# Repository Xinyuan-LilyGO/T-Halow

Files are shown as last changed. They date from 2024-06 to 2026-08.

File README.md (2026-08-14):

<h1 align = "center">🏆 T-Halow 🏆</h1>

<p> 
  
  
  
  
</p>

<!-- * [切换到中文版](./README_CN.md) -->

T-Halow is WiFi Halow, an optimized Wi-Fi solution for iot devices, which has a longer transmission distance while providing the same transmission power of 2.4GHz and 5GHz. T-Halow is equipped with the TX-AH module, which can operate in the 730M-950MHz band, the module can operate in the channel width of 1/2/4/8MHz, and can provide a physical throughput of 150 Kbps to 32.5Mbps.

# Project
There are two different versions of T-Halow, which differ in the way they are paired;

It is important to confirm the version of T-Halow you have.

| - | TIME | LINK | VIDEO |
| :---: | :---: | :---: | :---: |
| VER1 | V1.0 24-08-23 | [VERSION1](./docs/ver1/readme.md) | |
| VER2 | V1.0 24-04-16 | [VERSION2](./docs/ver2/readme.md) | https://www.youtube.com/watch?v=nM2GE8Imshc |

Version 1 and version 2 of T-Halow use the same [AT commands](./docs/AT_cmd.md).

Regarding the SDK of the TX-AH module, Taixin does not provide detailed API instructions. If you want to compile it yourself, you can use this project. [hgSDK](./SDK/hgSDK-v1.6.4.3-29063-wnb)

# Firmware download

If you need to download the TX AH firmware, you can use the following two methods:

| Download firmware via downloader  |[docs](./docs/Firmware_burn_1.md)|
| --- | --- |
| Download firmware via esp32 flash_download_tool  | [docs](./docs/Firmware_burn_2.md) |

# Official document;
TX-AH module official documentation is in Chinese, if you can speak Chinese, this may help you;

More TX-AH module information can be found on the official website，[download](https://taixin-semi.com/en/products/modules#wifi-halow)

| Frequency setting description | [docs](./hardware/TX_AH/泰芯802.11AH%20Frequency%20setting%20description_20231130110312.pdf) |
|:---:|:--- |
| TX-AH-Rx00P Series module technical specification | [docs](./hardware/TX_AH/泰芯802.11ah TX-AH-Rx00P%20Series%20module%20technical%20specification_20231116174457.pdf) |
| TX-AH-Rx00P Bridge instructions | [docs](./hardware/TX_AH//泰芯AH%20Bridge%20instructions_20230908122753.pdf) |
| AH Module AT instruction development guide | [docs](./hardware/TX_AH/泰芯AH%20Module%20AT%20instruction%20development%20guide_20230524100503.pdf) |
| AH Module development board instructions | [docs](./hardware/TX_AH/泰芯AH%20Module%20development%20board%20instructions_20230621205234.pdf) |
| AH Module hardware Design Guide | [docs](./hardware/TX_AH/泰芯AH%20Module%20hardware%20Design%20Guide_20230621170639.pdf) |
| AH Performance test method | [docs](./hardware/TX_AH/泰芯AH%20Performance%20test%20method_20230908122816.pdf) |
| AH-RF EMC Certification guide | [docs](./hardware/TX_AH/泰芯AH-RF EMC%20Certification%20guide_20230720140052.pdf) |

# TX-AH model comparison

| Module name | Front screen distinction | Overcertified condition | remark |
| :---: | :---: | :---: | :---: |
| TX-AH-R900P | Lower left P9, lower right P9  | Can pass FCC/CE certification | Supports 860MHz to 928MHz |
| TX-AH-R900PNR | Lower left P9, lower right NR |  Can pass FCC certification | Support 902MHz ~ 928MHz, with 915M Saw to improve receiving performance |
| TX-AH-R900PNR-860M | Lower left 86, lower right NR | Can pass CE certification | Support 859MHz ~ 894MHz, with 875M Saw to improve reception performance |

remark:
1. The difference between the P series module and the earlier A series module is:

(1) The bottom left screen print of the P series is beginning with P, and the bottom left screen print of the A series is beginning with R;

(2) P series PIN4/5 needs power supply, A series does not;

2. The module does not have a Shield by default. The name of the module with a shield is suffix-s, where S indicates shield.

## :three: Quick Start 🎁

🟢 PlatformIO is recommended because these examples were developed on it. 🟢 

### 1、PlatformIO

1. Install [Visual Studio Code](https://code.visualstudio.com/) and [Python](https://www.python.org/), and clone or download the project;
2. Search for the `PlatformIO` plugin in the `VisualStudioCode` extension and install it;
3. After the installation is complete, you need to restart `VisualStudioCode`
4. After opening this project, PlatformIO will automatically download the required tripartite libraries and dependencies, the first time this process is relatively long, please wait patiently;
5. After all the dependencies are installed, you can open the `platformio.ini` configuration file, uncomment in `example` to select a routine, and then press `ctrl+s` to save the `.ini` configuration file;
6. Click :ballot_box_with_check: under VScode to compile the project, then plug in USB and select COM under VScode;
7. Finally, click the :arrow_right:  button to download the program to Flash;

### 2、Arduino IDE

1. Install [Arduino IDE](https://www.arduino.cc/en/software)

2. Copy all files under `this project/lib/` and paste them into the Arduion library path (generally `C:\Users\YourName\Documents\Arduino\libraries`);

3. Open the Arduion IDE and click `File->Open` in the upper left corner to open an example in `this project/example/xxx/xxx.ino` under this item;

4. Then configure Arduion. After the configuration is completed in the following way, you can click the button in the upper left corner of Arduion to compile and download;

| Arduino IDE Setting | Value |
| --- | --- |
| Board | **ESP32S3 Dev Module** |
| Port | Your port |
| USB CDC On Boot | Enable |
| CPU Frequency | 240MHZ(WiFi) |
| Core Debug Level | None |
| USB DFU On Boot | Disable |
| Erase All Flash Before Sketch Upload | Disable |
| Events Run On | Core1 |
| Flash Mode | QIO 80MHZ |
| Flash Size | **16MB(128Mb)** |
| Arduino Runs On | Core1 |
| USB Firmware MSC On Boot | Disable |
| Partition Scheme | **16M Flash(3M APP/9.9MB FATFS)** |
| PSRAM | **OPI PSRAM** |
| Upload Mode | **UART0/Hardware CDC** |
| Upload Speed | 921600 |
| USB Mode | **CDC and JTAG** |

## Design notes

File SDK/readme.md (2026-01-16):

## T-Halow SDK Description

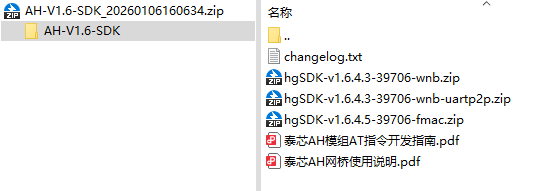
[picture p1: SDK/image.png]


The AH-V1.6-SDK package contains three AH module projects.
Each project can be compiled independently.

The AH-V1.6-SDK development environment requires the installation of the CDK environment.
For environment setup, please refer to 《泰芯TXW830x AH-SDK开发指南.pdf》.

The file descriptions are as follows:

| File | Description |
| :--- | :--- |
| hgSDK-v1.6.4.3-39706-wnb | -wnb corresponds to the Ethernet interface |
| hgSDK-v1.6.4.3-39706-wnb-uartp2p | -uartp2p serial port transparent transmission |
| hgSDK-v1.6.4.5-39706-fmac | -fmac corresponds to SDIO / UART / USB interfaces |
| 泰芯AH模组AT指令开发指南 | AT command description |
| 泰芯AH网桥使用说明 | Bridge configuration instructions |

`-wnb` is an Ethernet interface project. The main communication method is Ethernet communication, supporting TCP/UDP protocols with a communication speed of 90 Mbit/s.
The default serial port baud rate is 115200, which is used for sending and receiving AT commands and outputting debug information. It also supports a small amount of data transmission via the serial port.

`-uartp2p` is a serial port transparent transmission project. After successful pairing, data can be transmitted directly through the serial port. The transmission rate is affected by the serial port baud rate.
The default serial port baud rate is 115200. The baud rate can be modified by changing the `UART_P2P_BAUDRATE` definition.

Note that:

1. The packet length must be limited to 1500 bytes.

2. The baud rate should not be too high; otherwise, there is a risk of data loss. Generally, 400 kbps is recommended as an upper limit. At 921600, there is a relatively high risk of data loss.

`-fmac` is a communication project based on SDIO/SPI, UART, and USB interfaces. The primary communication methods are SDIO/SPI, UART, and USB. Taking SPI communication as an example, the data rate is approximately 25 Mbit/s.
The default serial port baud rate is 115200, which is used for sending and receiving AT commands and for outputting debug information. It also supports a small amount of data transmission via the serial port.

## T-Halow SDK Firmware Description

| File | Description |
| :--- | :--- |
| huge-ic-ah_v1.6.4.3-39706_wnb_sta_8.bin | **-wnb firmware**, maximum number of connected STAs is **8**, AT serial port baud rate **115200** |
| huge-ic-ah_v1.6.4.3-39706_wnb_sta_1.bin | **-wnb firmware**, maximum number of connected STAs is **1**, AT serial port baud rate **115200** |
| huge-ic-ah_v1.6.4.3-39706_wnb_uartp2p_baud_115200.bin | **-uartp2p** serial transparent transmission, baud rate **115200** |
| huge-ic-ah_v1.6.4.3-39706_wnb_uartp2p_baud_230400.bin | **-uartp2p** serial transparent transmission, baud rate **230400** |
| huge-ic-ah_v1.6.4.3-39706_wnb_uartp2p_baud_460800.bin | **-uartp2p** serial transparent transmission, baud rate **460800** |
| huge-ic-ah_v1.6.4.3-39706_wnb_uartp2p_baud_921600.bin | **-uartp2p** serial transparent transmission, baud rate **921600** |

## T-Halow Firmware Download

There is no interface on the T-Halow board for flashing firmware to the HaLow module, so the only option is to remove the HaLow module’s flash memory, place it into a programmer to download the firmware, and then reinstall the flash back to its original position after programming is complete.

Reference:

If you need to download the TX AH firmware, you can use the following two methods:

| Download firmware via downloader  |[docs](../docs/Firmware_burn_1.md)|
| --- | --- |
| Download firmware via esp32 flash_download_tool  | [docs](../docs/Firmware_burn_2.md) |

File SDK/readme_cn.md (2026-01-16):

## T-Halow SDK 说明



AH-V1.6-SDK 文件里面共包含三个 ah 模块的项目，每个项目可以独立编译；

AH-V1.6-SDK 编程环境需要安装 CDK 环境，环境搭建参考《泰芯TXW830x AH-SDK开发指南.pdf》

文件说明如下；

| 文件 | 说明 |
| :--- | :--- |
| hgSDK-v1.6.4.3-39706-wnb | -wnb 对应以太网接口 |
| hgSDK-v1.6.4.3-39706-wnb-uartp2p | -uartp2p 串口透传 |
| hgSDK-v1.6.4.5-39706-fmac | -fmac 对应 sdio uart usb 接口 |
| 泰芯AH模组AT指令开发指南 | AT 指令说明 |
| 泰芯AH网桥使用说明 | 网桥配置说明 |

`-wnb` 为以太网接口项目，主要通信方式为以太网通信，支持 tcp/upd 协议，通信速率为90mbit/s；默认串口波特率为 115200 用于收发 AT 指令，和输出调试信息，支持少量数据通过串口传输；

`-uartp2p` 为串口透传项目，配对成功后，可以直接通过串口传输数据，传输速率受串口波特率影响；串口默认波特率为 115200，可以更改 UART_P2P_BAUDRATE 定义来更改波特率；需要注意的是：

1. 包长要受限于1500字节。
2. 波特率不能太高，否则会有丢数风险，一般建议400k就不敢更高了，921600是有比较大丢数风险的

`-fmac` 为 sdio/spi、uart、usb 接口通信项目，主要通信方式为sdio/spi、uart、usb，以spi通信为例，通信速率为25mbit/s左右； 默认串口波特率为 115200 用于收发 AT 指令，和输出调试信息，支持少量数据通过串口传输；

## T-Halow SDK 固件说明

| 文件 | 说明 |
| :--- | :--- |
| huge-ic-ah_v1.6.4.3-39706_wnb_sta_8.bin | -wnb 固件，连接sta最大数量为8，at串口波特率115200 |
| huge-ic-ah_v1.6.4.3-39706_wnb_sta_1.bin | -wnb 固件，连接sta最大数量为1，at串口波特率115200 |
| huge-ic-ah_v1.6.4.3-39706_wnb_uartp2p_baud_115200.bin | -uartp2p 串口透传，波特率为 115200 |
| huge-ic-ah_v1.6.4.3-39706_wnb_uartp2p_baud_230400.bin | -uartp2p 串口透传，波特率为 230400 |
| huge-ic-ah_v1.6.4.3-39706_wnb_uartp2p_baud_460800.bin | -uartp2p 串口透传，波特率为 460800 |
| huge-ic-ah_v1.6.4.3-39706_wnb_uartp2p_baud_921600.bin | -uartp2p 串口透传，波特率为 921600 |

## T-Halow 固件下载

T-Halow 上面没有为 Halow 模块烧录固件的接口，所以只能将 Halow 模块的flash 去下，放入烧录器中下载程序，烧录完程序后再将 flash 放回原来的位置；

参考：

If you need to download the TX AH firmware, you can use the following two methods:

| Download firmware via downloader  |[docs](../docs/Firmware_burn_1.md)|
| --- | --- |
| Download firmware via esp32 flash_download_tool  | [docs](../docs/Firmware_burn_2.md) |

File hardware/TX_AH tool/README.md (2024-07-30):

This article is taken from: TX_AH\泰芯AH Bridge instructions_20230908122753.pdf

2.2 Flow test method

2.2.1 Preparing Tools

- Two windows PCS with cable network ports. (If no cable network port is available, switch from usb to cable network port.

Can also)

- Two network cables

- A pair of Thai core bridge (including host, antenna, 5v power supply) successfully paired according to the pairing method section.

- jperf(provided by contact FAE)

2.2.2 Traffic test method

2.2.2.1 The first step is to connect the computer to the network bridge using network cables

Connect a computer with a network cable to a bridge

Use a second cable to connect the other computer to the bridge

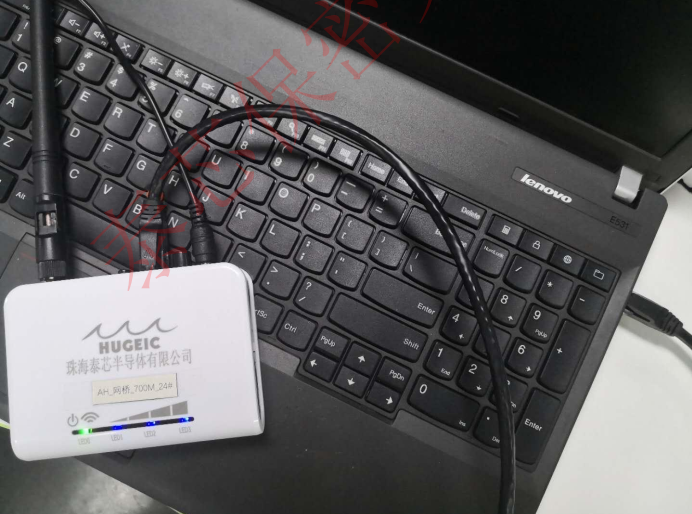
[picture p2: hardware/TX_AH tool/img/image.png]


2.2.2.2 Step 2 Configure wired network ip addresses for the two computers

Open `Control Panel \ Network and Internet\ Network and Sharing Center` Click Ethernet as shown below

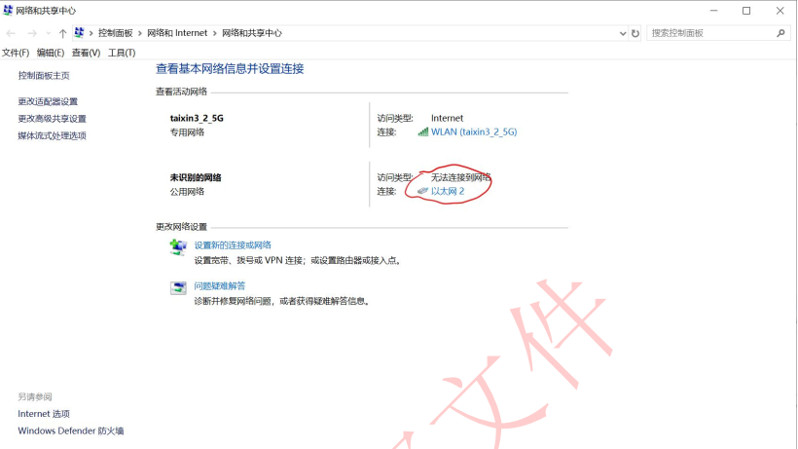
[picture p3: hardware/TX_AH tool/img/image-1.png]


Click properties as shown below

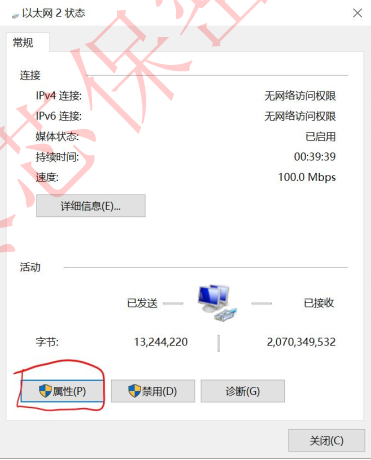
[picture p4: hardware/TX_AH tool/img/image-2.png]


Click the internet Protocol version option and click Properties as shown below

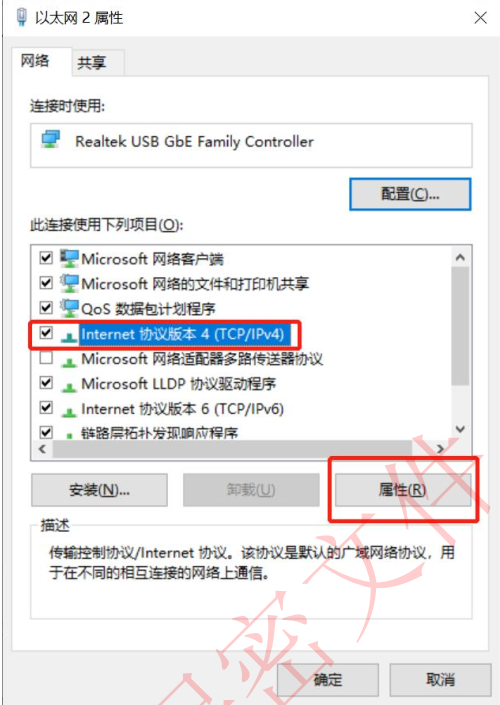
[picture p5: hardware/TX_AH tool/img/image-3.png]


Configure the IP address of the cable network. For example, set the IP address to `10.10.10.156` on one PC and `10.10.10.123` on the other PC

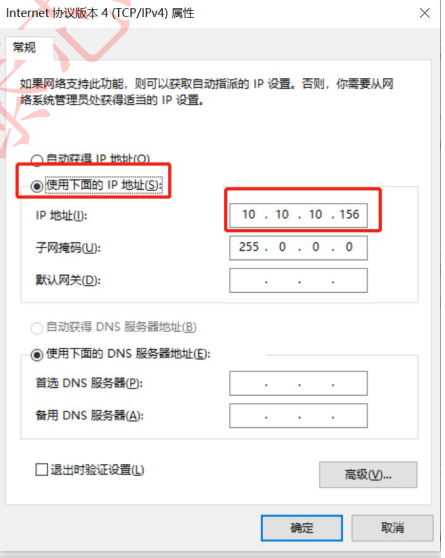
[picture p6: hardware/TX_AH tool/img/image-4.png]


2.2.2.3 Step 3 Disable the firewall temporarily

If iperf is used as the traffic test method, disable the firewall; otherwise, the traffic test cannot be performed.

The following only describes the method of closing the firewall of windows. For the firewall of other security software, please find the method of closing:

1. `win+r` to bring up the running screen, enter cmd, and press Enter
2. In the cmd window that is displayed, enter `Firewall.cpl` and press Enter
3. In the firewall page that pops up, click "Enable or disable Windows Defender Firewall" options

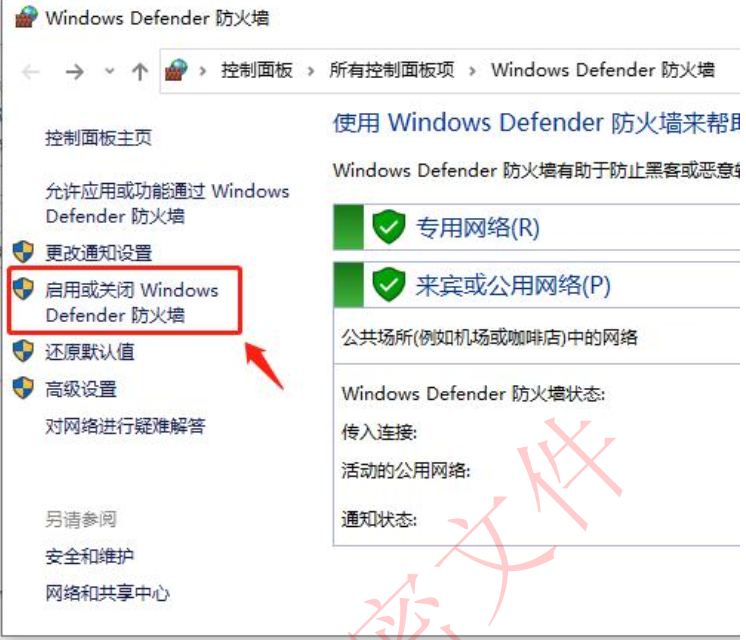
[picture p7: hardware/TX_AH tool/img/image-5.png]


4. In the pop-up "Custom Settings" page, select the "Turn off Windows Defender Firewall" option for all, and then click OK

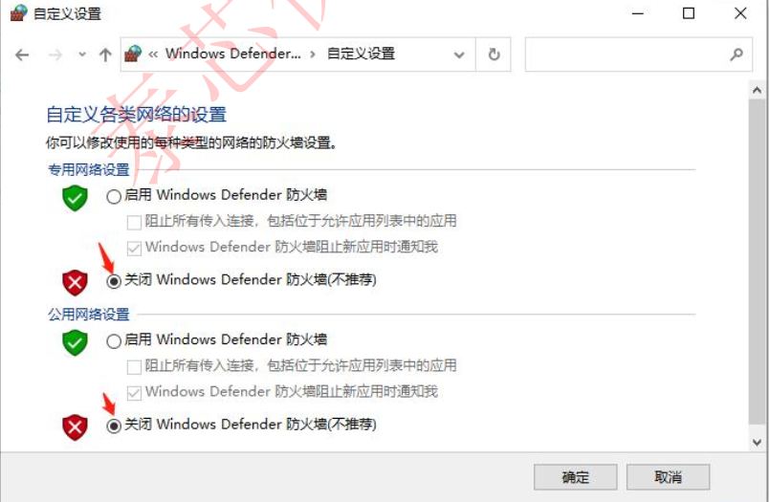
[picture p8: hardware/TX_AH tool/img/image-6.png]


5. After the traffic test is complete, enable the firewall again on the page shown in Step 4.

2.2.2.4 Step 4 Run the jperf to send traffic

1.tcp test:

Run jperf on the first computer (ip address 10.10.10.156, bridge in ap mode). transport layer options Select tcp(tcp by default). Choose iperf mode :server, that is, as the server. Then click run iperf.

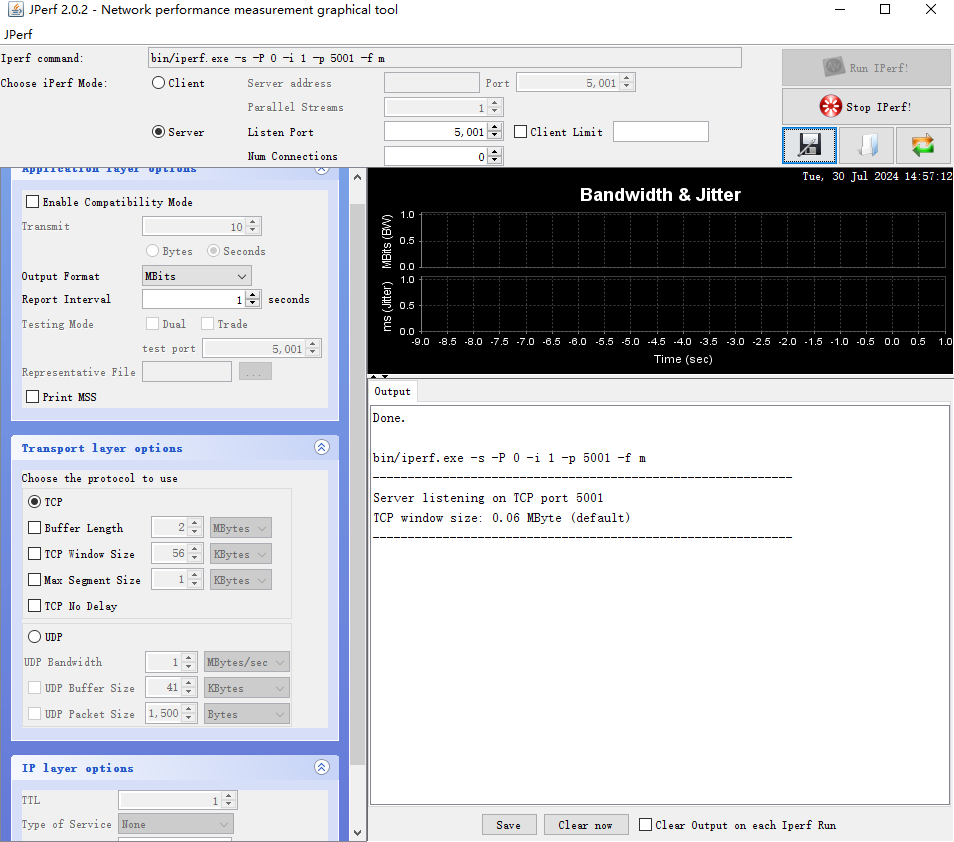
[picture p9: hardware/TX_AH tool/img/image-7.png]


Run jperf on the second computer (ip address 10.10.10.123, bridge in sta mode). transport layer options Select tcp(tcp by default).

Choose iperf mode :client, that is, as the client. Server adress enters the ip address of the other computer, which is 10.10.10.156. Port 5001 is the default port number. The port number on the server and client must be the same.

You can change the traffic test duration (for example, 600 seconds) in the transmit item of the Application layer options. Set output format to a traffic unit, for example, Mbits. Then click run iperf.

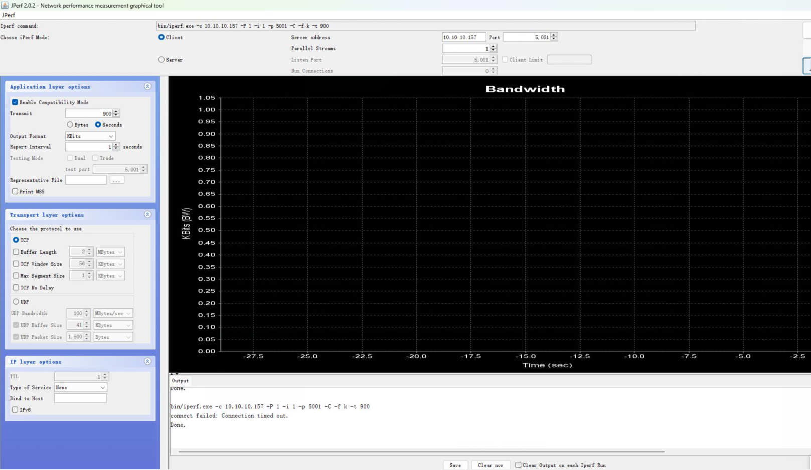
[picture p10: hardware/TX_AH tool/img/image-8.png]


2.udp test

As with the tcp test, the first computer runs jperf and selects udp in the transport layer options.

Choose iperf mode :server, as the server, and click run iperf.

Run jperf on the second computer and select udp in transport layer options.

Choose iperf mode :client. That is, as the client, set udp bandwidth to

100 (default is 1). Server adress Enter the ip address of the other computer. Port 5001 is the default port number, the same for the server and the client, and then click run iperf. Observe the traffic data on the server.

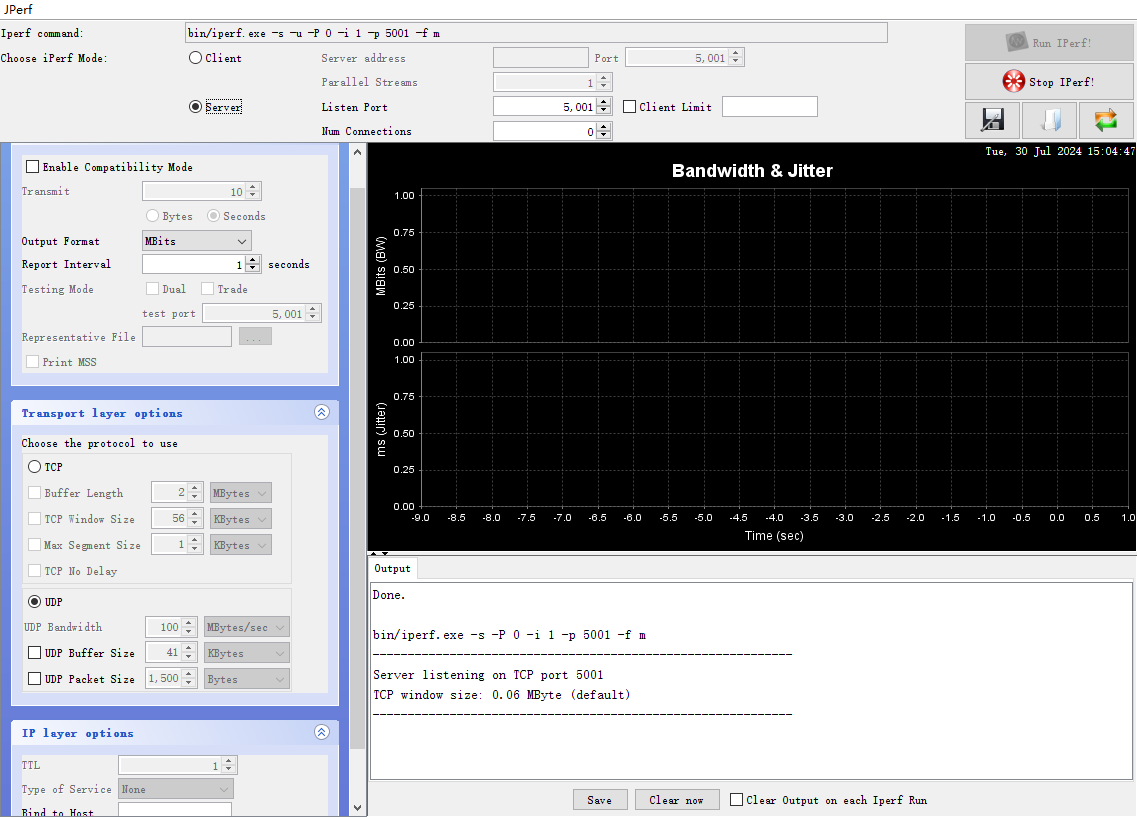
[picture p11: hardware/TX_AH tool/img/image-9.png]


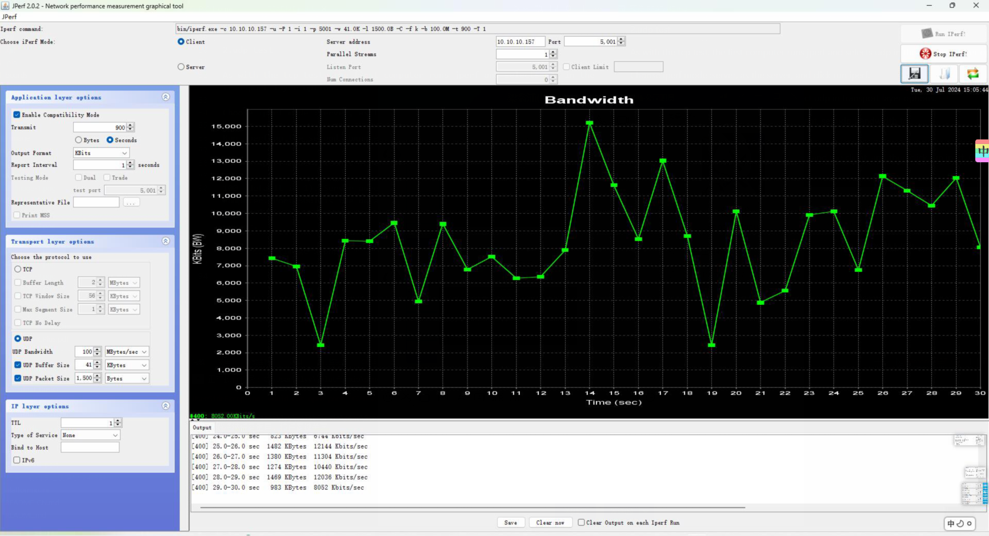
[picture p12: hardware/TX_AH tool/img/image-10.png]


At present, the bridge design is sta to the ap direction of traffic priority, if the exchange of traffic direction to ap to sta direction, the traffic will be slightly smaller

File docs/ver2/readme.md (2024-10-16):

# T_Halwo Version2

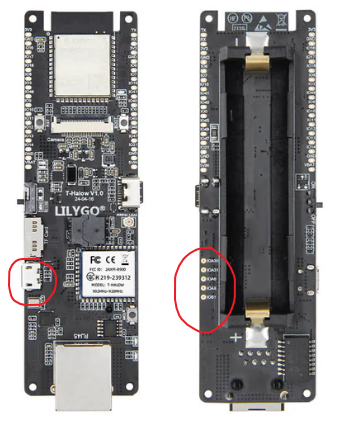
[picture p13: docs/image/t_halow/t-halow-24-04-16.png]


T-Halow operates in two modes:

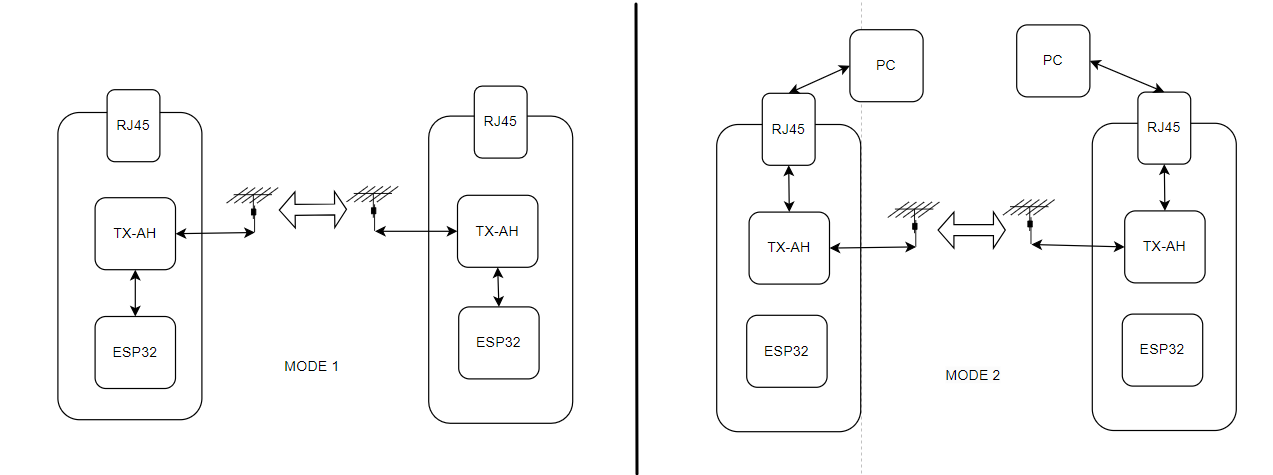
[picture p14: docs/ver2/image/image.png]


The two modes differ：

~~~
MODE1: Send AT command control to TX-AH via ESP32
    TX-AH: Download huge-ic-ah_xxxxxxxxx_TAIXIN-usb.bin
    ESP32: Download AP or STA
    Notice：Debug using Type-C

MODE2: Send AT command control via micro-USB
    TX-AH: download huge-ic-ah_xxxxxxxxx_TAIXIN-WNB.bin
    ESP32: No firmware download required
    Notice：Debug using Micro-USB
~~~

Firmware file path `firmware\version2`.



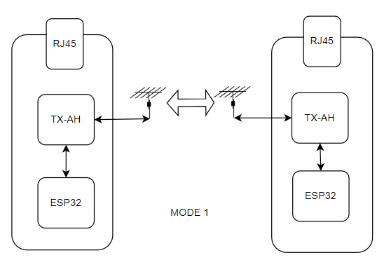
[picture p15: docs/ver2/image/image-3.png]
| T-Halow starts with MODE 1 | [docs](../mode1_test.md)  |  |
| --- | --- | --- |
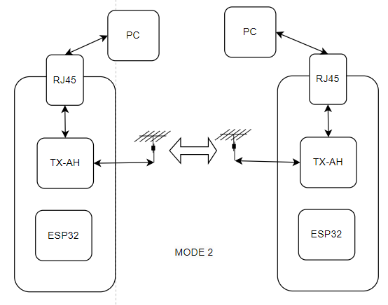
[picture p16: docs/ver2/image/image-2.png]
| T-Halow starts with MODE 2 | [docs](../mode2_test.md)  |  |
| TX-AH module pairing | [docs](./module_pair.md) |

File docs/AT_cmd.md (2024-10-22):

# AT 命令

Taixin AH module supports AT command working mode, and can send AT command through uart Data setting, data communication.

Note Select the new line mode in the serial port tool, and the AT command is case insensitive.

# Basic networking commands

## `AT+MODE`

Set the working mode；AT+MODE=[param]；Supports parameter : ap / sta / group / apsta

example：

```txt
AT+MODE?		// Inquire
AT+MODE=AP      // AP mode
AT+MODE=STA  	// STA mode 
AT+MODE=GROUP	// Multicast/broadcast mode, see description of `JOINGROUP`
AT+MODE=APSTA	// In trunk mode, the device in trunk mode connects to the 
				// upper-level AP as a sta and provides connection services 
				// for other STAs as an ap. Use `at+r_ssid` and `at+r_psk` to set 
				// connection parameters for the upper AP.
```

## `AT+SSID`

Set the SSID；AT+SSID=[ssid_char]；ssid_char contains less than 32 characters

example：

```txt
AT+SSID? 				// Inquire
AT+SSID=hgic_ah_test	// Set the SSID to `hgic_ah_test`
```

## `AT+KEYMGMT`

Set encryption mode；AT+KEYMGMT=[param]；Supports parameter : WPA-PSK/NONE

example :

```txt
AT+KEYMGMT?			// Inquire
AT+KEYMGMT=WPA-PSK	// Enable encryption
AT+KEYMGMT=NONE		// Turn off encryption
```

## `AT+PSK`

Set encryption password；AT+PSK=[psk_char]；psk_char must be 64 hex characters. If the setting does not meet the length requirements, the previous will be cleared Save the PSK

example：

```txt
AT+PSK?																		// Inquire
AT+PSK=baa58569a9edd7c3a55e446bc658ef76a7173d023d256786832474d737756a82		// Set encryption password
```

## `AT+PAIR`

Pairing control；AT+PAIR=[0/1]

This command can achieve quick pairing and network configuration when the SSID is not set. When pairing starts:

1. The AP has configured the SSID and password, but the STA has not: During the pairing process, the STA will obtain the AP's SSID and password.

2. Both the AP and the STA have not configured the SSID and password: During the pairing process, the AP will generate a random password for each STA.

A PAIR SUCCESS message will be generated after the pairing is successful, but the pairing will not automatically terminate. The pairing must be stopped by executing `AT+PAIR=0`.

The connection will be established automatically after the pairing is stopped.

If both the AP and the STA have set the SSID and other parameters, the PAIR does not need to be started. The connection will be established automatically based on the SSID and other parameters.

example：

```txt
AT+PAIR=1 	// Start pairing
AT+PAIR=0 	// Stop pairing
```

## `AT+BSS_BW`

Set the BSS bandwidth；AT+BSS_BW=[bss_bw]；Supports parameter：1 / 2 / 4 / 8

```txt
AT+BSS_BW?		// Inquire
AT+BSS_BW=1		// Set the bandwidth to 1
AT+BSS_BW=2		// Set the bandwidth to 2
AT+BSS_BW=4		// Set the bandwidth to 4
AT+BSS_BW=8		// Set the bandwidth to 8
```

## `AT+FREQ_RANGE`

Set the operating frequency range；AT+FREQ_RANGE=[start,end]；

This command is used to set the frequency range for continuous use and specify the start and end center frequency. The AH module automatically calculates the frequency list.

Note：that if `AT+CHAN_LIST` is also set, the CHAN_LIST parameter takes precedence

example:

```txt
AT+FREQ_RANGE?				// Inquire
AT+FREQ_RANGE=9080,9240	 	// start freq 908Mhz, end freq 924Mhz
```

## `AT+CHAN_LIST`

Set the working frequency list；AT+CHAN_LIST=[freq1, freq2, ...]；

This command is used to set the non-continuous frequency list. Supports a maximum of 16 frequency points separated by commas (,)

```txt
AT+CHAN_LIST?					// Inquire
AT+CHAN_LIST=9080, 9160, 9240	// Set three frequency points: 908MHz,916MHz,924Mhz
```

# Status query command

## `AT+RSSI`

Check the device signal quality RSSI；AT+RSSI=[index/mac_addr]

Parameter description：

* index：Specify the device index to be queried, starting from 1
* mac_addr：Specify the mac address of the device to be queried

example：

```txt
AT+RSSI?  					// Query the rssi of the first device
AT+RSSI=1					// Query the rssi of the first device
AT+RSSI=f4:de:09:68:6c:20	// Query the RSSI by MAC address
```

## `AT+CONN_STATE`

View connection status；

example：

```txt
AT+CONN_STATE
```

## `AT+WNBCFG`

View device parameters；

example：

```txt
AT+WNBCFG
```

## `AT+SCAN_AP`

Scan for AP information；

This command is executed in STA mode to scan for AP information.

After scanning, query the results with the following BSSLIST command.

example：

```txt
AT+SCAN_AP=2
```

## `AT+BSSLIST`

Get the list of scanned aps;

After running the scan_ap command, you can use this command to obtain the AP list to be scanned. (The ap can be scanned only after ssid is set.)

example：

```txt
AT+BSSLIST
```

# Advanced networking commands

## `AT+TXPOWER`

Set the maximum transmit power；AT+TXPOWER=[txpower]；The range of txpower is [6 , 20]

example：

```txt
AT+TXPOWER?		// Inquire
AT+TXPOWER=20	// Set transmit power 20dbm
```

## `AT+ACKTMO`

Set the ACK TIMEOUT period；AT+ACKTMO=0；Default value. No additional ACK timeout period is added

Parameter description：

Set the WiFi protocol parameter ack timeout value of the AH module. The unit is microsecond. The default value is 0.

You need to set this parameter only when the communication exceeds 1km.

The formula is 10* (distance in kilometers -1), for example 2km set acktmo=10.

Modified value Power-off Save.

example：

```txt
AT+ACKTMO?		// Inquire
AT+ACKTMO=10	// Increase the ACK packet timeout period by 10us
```

## `AT+TX_MCS`

Set the TX MCS；AT+TX_MCS=255；Default value is 255, auto MCS；The value ranges [0, 7]

Parameter description：

Set tx mcs. When the value ranges from 0 to 7 or 1M, 10 indicates that the mcs is fixed. Other values indicate that the mcs is automatically adjusted.

Modified value Power-off Save.

example：

```txt
AT+TX_MCS?		// Inquire
AT+TX_MCS=2 	// The MCS for fixed transmission is 2
```

## `AT+HEART_INT`

Set the heartbeat packet interval；AT+HEART_INT=500；Default value is 500；

Parameter description：

Set the heartbeat packet interval (unit: mS) to 500. The larger the number of STAs, the larger the recommended heartbeat packet interval. The approximate length of heartbeat packets is STA_count x 50

V1.6.2 As long as the AP heartbeat packet interval can be set, the AP will automatically synchronize to the STA, this command is invalid for the STA

Modified value Power-off Save.

example：

```txt
AT+HEART_INT?			// Inquire
AT+HEART_INT=2000		// Set the heartbeat packet interval to 2S
```

## `AT+UNPAIR`

Set unpair a specified STA；AT+UNPAIR=[mac_addr]；mac_addr is the mac address of the peer；

example：

```txt
AT+MAC_ADDR=?					// View the MAC address of the device
AT+UNPAIR=f6:de:09:75:a3:61		// Unpair
```

# Debugging command

## `AT+LOADDEF`

factory data reset；

example：

```txt
AT+LOADDEF=1
```

## `AT+SYSDBG`

Set print debugging information；AT+SYSDBG=XXX,VALE；

Parameter description：

* XXX：Optional value LMAC / WNB

  * LMAC：Air interface statistics
  * WNB：Network layer statistics
* VALE：Optional value 0 / 1

  * 0：Close corresponding print
  * 1：Opencorresponding print

example：

```txt
AT+SYSDBG=LMAC,0	// Disable LMAC printing
```

# Multicast related commands

## `AT+JOINGROUP`

Adding a multicast network；AT+JOINGROUP=group_addr,AID；

Notice the JOINGROUP command can be configured only after the `AT+MODE=GROUP` mode is set.

Parameter description：

* group_addr：Specifies the address of the multicast network to be added
* AID：The AID value of the device in the multicast network ranges from 1 to N (N is the maximum number of STAs supported by the firmware). The AID of each device on the network should be unique.

  * Set valid AID: The WiFi module will periodically send a heartbeat in the multicast network to announce its existence to other WiFi modules
  * Invalid AID: The WiFi module does not send a heartbeat or notify other WiFi modules. **If AID is set to 0 for all devices, there is no limit to the maximum number of STAs supported by the firmware**.

After setting the working mode of the WiFi module to group, you can run this command to add the WiFi module to a multicast network.

After joining a multicast network, the WiFi module will only receive data from that multicast network.

All data communications are communicated at multicast addresses. If the working mode is set to group, but the multicast network is not added, all data communication is transmitted in broadcast mode

example：

```txt
AT+JOINGROUP=11:22:33:44:55:66,3	// group_addr=11:22:33:44:55:66
									// AID=3
```

# Relay station commands

## `AT+R_SSID`

Set relay station SSID；AT+R_SSID=repeater_ssid；Set the relay to connect to the SSID of the upper-level AP；

Note：Currently only supports the first-level relay

example：

```txt
AT+R_SSID?					// Inquire
AT+R_SSID=repeater_ssid		// Set the relay to connect to the SSID of the upper-level AP
```

## `AT+R_PSK`

Set the relay encryption password；AT+R_PSK=psk_char；

Parameter description：

The password for the relay to connect to the upper AP. psk_char must be 64 hex characters.

example：

```txt
AT+R_PSK? 		// Inquire
AT+R_PSK=baa58569a9edd7c3a55e446bc658ef76a7173d023d256786832474d737756a82 		//must be 64 hex characters
```

# Roaming related commands

## `AT+ROAM`

Set the roaming enable；AT+ROAM=0/1；

Roaming only needs to be enabled on the STA side. The SSID of the AP in the roaming network can be set by full word matching or fuzzy matching.

Full word matching: The SSID of all APs is set to the same SSID. The SSID length is not limited, and it can be no more than 32 characters. STAs are also set to this SSID.

Fuzzy matching: The last 3 characters of the SSID of different APs are different. The total length of the SSID must be greater than 8 characters, and it consists of a common string (at the beginning of the SSID string) and a 3-character ID (at the end of the string). For example, if the common string is HUGE_IC_AH, then the SSID of AP1 can be set to HUGE_IC_AH001, the SSID of AP2 can be set to HUGE_IC_AH002, and so on.  
The STA's SSID must be set to be the same as the SSID of one of the APs.

example：

```txt
AT+ROAM?		// Inquire
AT+ROAM=0		// Disable
AT+ROAM=1		// Enable
```

# Hibernation related commands

## `AT+PS_MODE`

Set STA sleep mode；AT+PS_MODE=0/1/2/3/4；

Parameter description：

* 0:  No sleep mode is set, the effect is the same as mode 3.

* 1: When the module enters sleep, it keeps alive with the server (the module keeps alive with the server itself).

* 2: When the module enters sleep, it keeps alive with the server (the AP keeps alive with the server instead of the module, with the lowest power consumption).

* 3: When the module enters sleep, it only maintains a connection with the AP, and any unicast packet can wake up the module.

* 4: When the module enters sleep, it only keeps alive with the AP, and can only be awakened by the AP input: `AT+WAKEUP`.

example：

```txt
AT+PS_MODE?
```

# Other Command

## `AT+VERSION=?`

View the firmware version.

## `AT+MAC_ADDR=?`

View the MAC address of the device.

## `AT+TXDATA`

Send data instruction；AT+TXDATA\=[length,txbw,txmcs,priority]；

Parameter description：

* length: the length of the data to be sent [required]

* txbw: specifies the tx bandwidth of the data [optional]

* txmcs: specifies the tx mcs of the data [optional]

* priority: specifies the priority of the data, 0~7 [optional]

This command is used to send data through the serial port when the UART is in non-transparent mode.

Execution steps:

1. First execute the AT+TXDATA command to set the parameters for data transmission.
2. After executing the at+txdata command and it returns OK, data transmission starts. The length of the transmitted data must meet the length specified by the parameter.

The default firmware is 1-to-many mode. In 1-to-many mode, AT+TXDATA cannot send the original data directly. It needs to add 14Byte Ethernet frame header before the original data and then send it. The length setting should also include the Ethernet frame header length.

example：

### Test 1: Simple test

Send the command `at+txdata=24` first, then send the data `111111000000001234567890` after receiving OK.

```txt
at+txdata=24 					// 14 byte Ethernet frame header + 10 byte data
111111000000001234567890		// The actual data sent
```

* 111111: 	Ethernet destination address

* 000000: 	Ethernet source address

* 00:	Ethernet protocol type, Can be filled with 0

* 0123456789:	Data to be sent

Write in hex: 31 31 31 31 31 31 30 30 30 30 30 30 30 30 31 32 33 34 35 36 37 38 39 30

### Test 2: Specify the MAC address of the device to send data

Assumption:

* Destination MAC: 4a:06:59:a5:81:98

* Source address MAC: 4a:06:59:7b:6c:98

* Sent data: 1234567890

```txt
at+txdata=24 		// 14 byte Ethernet frame header + 10 byte data
4A 06 59 A5 81 98 4A 06 59 7B 6C 98 30 30 31 32 33 34 35 36 37 38 39 30		// The actual data sent
```

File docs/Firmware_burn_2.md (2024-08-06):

# Download firmware using esp32

1、Find a working esp32 board with flash encapsulated in SOP8

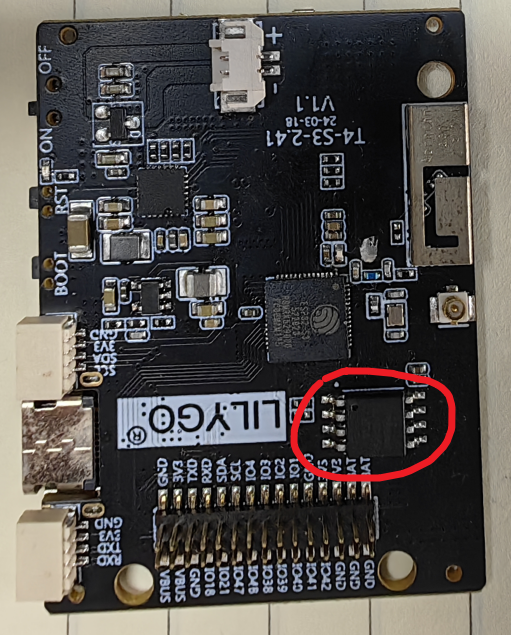
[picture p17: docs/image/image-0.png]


2、Use the [flash_download_tool](https://www.espressif.com/en/support/download/other-tools) download tool，Download firmware：[Firmware](https://github.com/Xinyuan-LilyGO/T-Halow/tree/master/firmware)

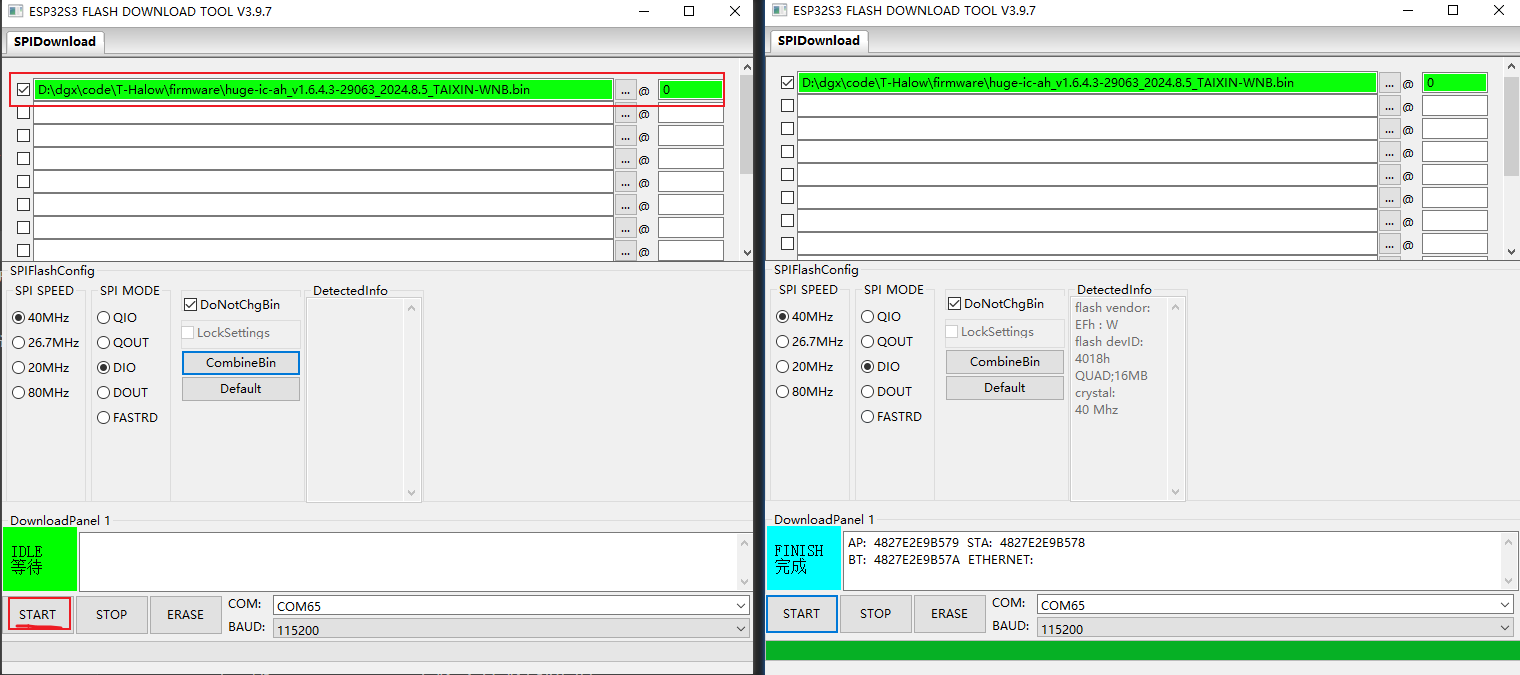
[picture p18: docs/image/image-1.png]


3、Then remove the flash from the esp32 board and put it into the seat of T-Halow; (Pay attention to clean up the flash chip to avoid T-Halow seat.)

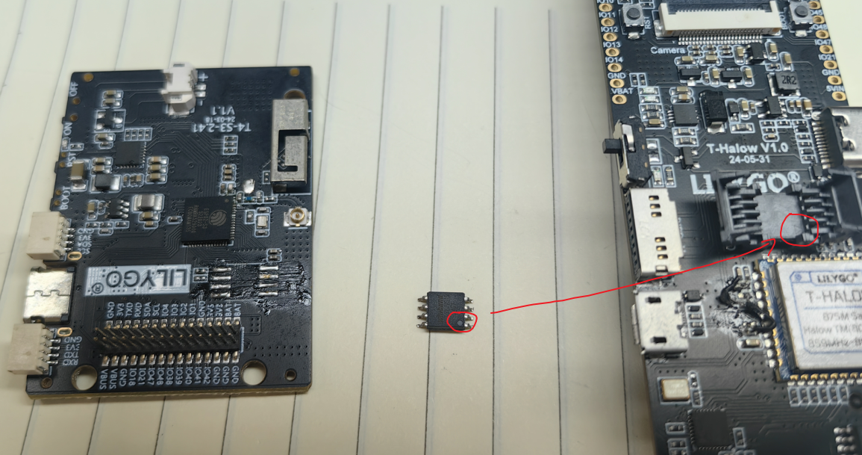
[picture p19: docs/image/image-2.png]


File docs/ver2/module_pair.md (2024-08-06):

To pair two TX-AH-RX00Ps, follow the following steps:

1. Check the screen printing on the lower right corner of the module. 7P means 700M, 868 means 868M, and 9P means 900M. Only modules with the same transmission frequency can be successfully equipped.

2. Suppose to use two modules that have downloaded USB firmware 7P of the development board, connect the two modules to the serial port, use the `AT+MODE=ap` command to set one device to ap mode, and use the `AT+mode=sta` command to set the other device to sta mode

3. When pairing, the AP device and STA device need to use the `AT+PAIR=1` command `AT+PAIR=0` command to stop the pairing

4. Note: The print serial port of USB firmware is A10/A11, and the print serial port of other firmware is A12/A13

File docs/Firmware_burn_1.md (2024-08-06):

# Download using the downloader

Let's take FLY SP10B as an example;

1、Downloader using FLY SP10B, [software download address](https://www.sflytech.com/Download/Software/), Download software [FlyPRO Ⅱ](https://www.sflytech.com/html/3128973325.html), place the Flash chip as follows; Then connect the downloader to your computer;

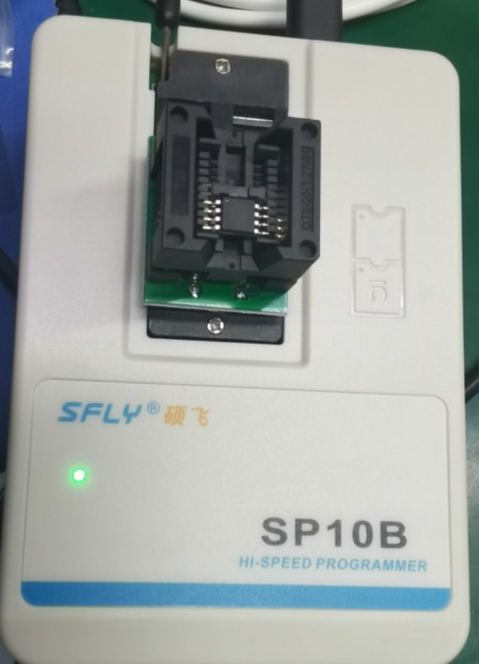
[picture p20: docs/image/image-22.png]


2、Download the latest `hugc-ic-ah-xxxxxxxxxxxx.bin` firmware from [Github](https://github.com/Xinyuan-LilyGO/T-Halow/tree/master/firmware);

3、Open FlyPRO II, click Chip -> Identify chip model -> Then select the corresponding Flash chip model;

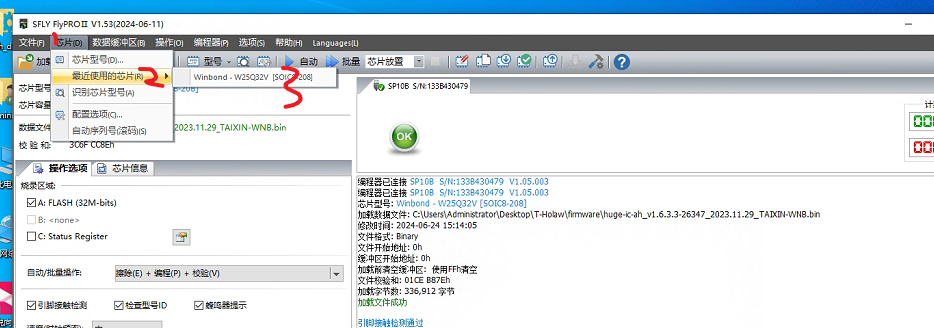
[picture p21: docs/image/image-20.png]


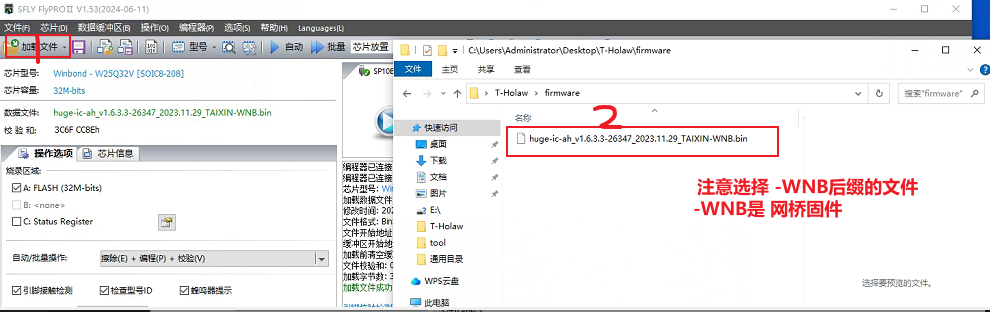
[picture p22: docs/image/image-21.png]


Download usb firmware `hugc-ic-ah-xxxxxxxxxxxx.bin` to Flash with downloader; After downloading, place the Flash chip on the T-Halow seat;

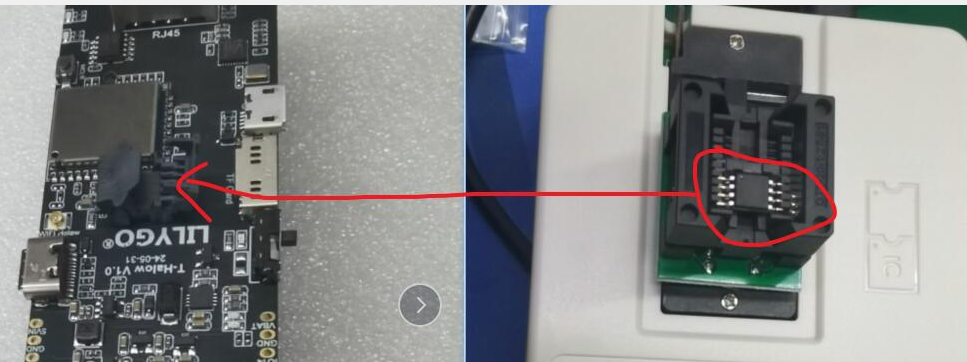
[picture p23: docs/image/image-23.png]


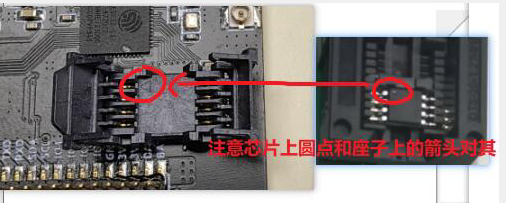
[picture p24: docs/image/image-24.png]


After the firmware download is complete, plug in Type-C and Micro-USB, and then use the serial port to open the COM port, and then send `AT+` to test whether the TX-AH firmware is downloaded successfully;



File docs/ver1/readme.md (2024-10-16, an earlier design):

# T_Halwo Version1

|Added signal indicator| Add pairing and mode switching buttons |
|:---:|:---:|
|  |  |

# T-Halow networking mode:

The following networking modes are supported:

1. [Ap-STA](./network_mode/1_AP-STA.md) mode, basic star network, one AP connects multiple STAs; The maximum number of STAs supported can be configured by firmware, the default firmware supports a `maximum of 8 STAs`, and can be configured to support a maximum of 32 STAs (need to modify the firmware).

2. [AP-Relay-STA](./network_mode/2_AP-Relay-STA.md) mode, adding relay nodes to the basic star network to extend the distance, but the maximum flow will be halved; `Currently only supports the first-level relay`.

3. [AP-STA-net-AP-STA](./network_mode/3_AP-STA-net-SP-STA.md) mode, Extending communication distance via network cable.

4. Use [AT+ROAM](../AT_cmd.md##`AT+ROAM`) to enable roaming. The roaming function supports STA roaming between APs. STA will automatically select a stronger AP based on the signal conditions.

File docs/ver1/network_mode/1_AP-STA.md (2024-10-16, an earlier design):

How to pair an AP with multiple STAs.

One AP connects to multiple STAs; **`by default, it supports up to 8 STAs`**



# ESP32

ESP32 downloads AT_test firmware, only serial port forwarding;

AT_test program path `example\AT_test.ino`

# PAIR

Before pairing, use the `AT+LOADDEF=1` command to reset each T-Halow to prevent them from automatically connecting to each other (If a T-Halow has been paired before, it will automatically pair when powered on again).

Use the latest T-Halow, turn the rear switch to AP/STA mode. In case of multiple T-Halows, only one needs to be set as AP and the others as STA.



First, long press the PAIR button of No.1 and No.2 until the CONNECT light flashes quickly, then release it. When the connection is successful, the CONNECT light will be on.



Then pair No.1 with No.3, also long press the PAIR button, the CONNECT light flashes quickly, and then release it. After the pairing is successful, the CONNECT light is always on.

The same operation is performed on the other STAs No.1 and No.N until all STAs are connected to the AP.

# CONFIG ADDR

Finally, assign an address to each T-Halow. Taking `10.10.10.156` and `10.10.10.123` as examples, set the address of T-Halow.

After all T-Halows are assigned addresses, they can ping each other to verify whether they can communicate.

Open `Control Panel \ Network and Internet\ Network and Sharing Center` Click Ethernet as shown below

Configure the IP address of the cable network. For example, set the IP address to `10.10.10.123` on one PC



Set the IP address of the other PC to `10.10.10.156`



Then turn off the PC's firewall and do not connect the PC to WIFI.

After the connection is successful, press `win+r`, enter `cmd` to develop the command line window, and then ping each other;



Development of serial tools, a device set to server



The other device is set to client



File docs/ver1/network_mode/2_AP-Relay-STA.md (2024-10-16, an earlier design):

How to configure relay mode using T-Halow.

**`Currently only supports the first-level relay`**.

As shown in the figure below, this is true. the following describes how to configure these T-Halow



Before pairing, use the `AT+LOADDEF=1` command to reset each T-Halow to prevent them from automatically connecting to each other (If a T-Halow has been paired before, it will automatically pair when powered on again).

# ESP32

ESP32 downloads AT_test firmware, only serial port forwarding;

AT_test program path `example\AT_test.ino`

# PAIR
**1. AP**

Configure the AP's ssid. Each AP should have a different configuration. You can consider increasing it by ssid1 and ssid2. For example:
~~~
at+ssid=ssid1
~~~

Configure non-encryption (to simplify the configuration, temporarily use non-encryption as an example)

~~~
at+keymgmt=none
~~~

**2. APSTA**

Configuring the role of a relay

~~~
at+mode=apsta
~~~

Configure no encryption

~~~
at+keymgmt=none
~~~

Configure the relay's r_ssid, which is used to connect the relay to the AP. It should be consistent with the ssid of the AP you want to connect to, for example:

~~~
at+r_ssid=ssid1
~~~

Configure the relay's ssid to connect the relay to the sta. For ease of management, you can consider making the front ssid consistent with the ap's ssid and adding a suffix at the end, such as ssid1_r1, ssid1_r2, ssid2_r1, etc. For example:

~~~
at+ssid=ssid1_r1
~~~

**3. STA**

Configure the STA's ssid to connect to the relay. It should be consistent with the ssid of the relay you want to connect to, for example:

~~~
at+ssid=ssid1_r1
~~~

Configure no encryption

~~~
at+keymgmt=none
~~~

# CONFIG ADDR

Open `Control Panel \ Network and Internet\ Network and Sharing Center` Click Ethernet as shown below

Configure the IP address of the cable network. For example, set the IP address to `10.10.10.123` on one PC



Set the IP address of the other PC to `10.10.10.156`



Then turn off the PC's firewall and do not connect the PC to WIFI.

After the connection is successful, press `win+r`, enter `cmd` to develop the command line window, and then ping each other;



Development of serial tools, a device set to server



The other device is set to client



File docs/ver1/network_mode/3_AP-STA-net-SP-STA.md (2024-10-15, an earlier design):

How to configure multiple T-Halows in relay mode.

The following figure shows an example of how to configure each T-Halow.



# ESP32

ESP32 downloads AT_test firmware, only serial port forwarding;

AT_test program path `example\AT_test.ino`

# PAIR

There are four T-Halow devices in total. Before pairing, use the `AT+LOADDEF=1` command to reset each T-Halow to prevent them from automatically connecting to each other (If a T-Halow has been paired before, it will automatically pair when powered on again).

After resetting each T-Halow using `AT+LOADDEF=1`, then connect No.1 and No.4 to the PC with an Ethernet cable, and No.2 and No.4 to each other with an Ethernet cable.

Set No.1 and No.3 to AP mode, and No.2 and No.4 to STA mode.

Use the latest T-Halow, turn the rear switch to AP/STA mode, and then restart the machine.



After confirming that the mode of each T-Halow is set correctly, use the PAIR key to pair them.

Press and hold the PAIR buttons No.1 and No.2 until the CONNECT light flashes, then release them. The same goes for numbers No.3 and No.4.



# CONFIG ADDR

Open `Control Panel \ Network and Internet\ Network and Sharing Center` Click Ethernet as shown below

Configure the IP address of the cable network. For example, set the IP address to `10.10.10.123` on one PC



Set the IP address of the other PC to `10.10.10.156`



Then turn off the PC's firewall and do not connect the PC to WIFI.

After the connection is successful, press `win+r`, enter `cmd` to develop the command line window, and then ping each other;



Development of serial tools, a device set to server



The other device is set to client



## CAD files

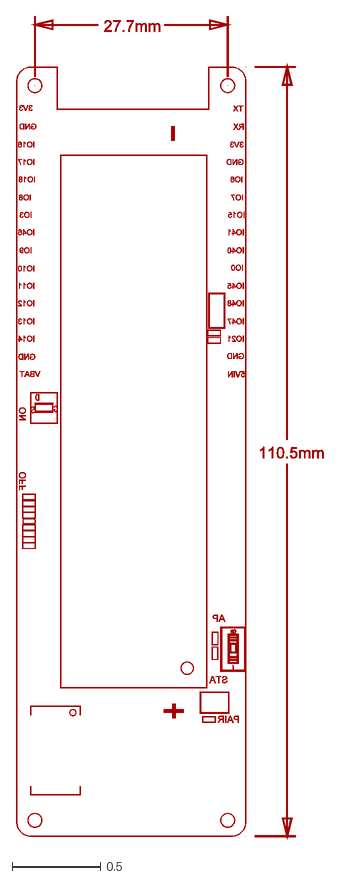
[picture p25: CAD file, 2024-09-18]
hardware/T-Halow V1.0 - BOTTOM.dxf
1.74 x 4.66

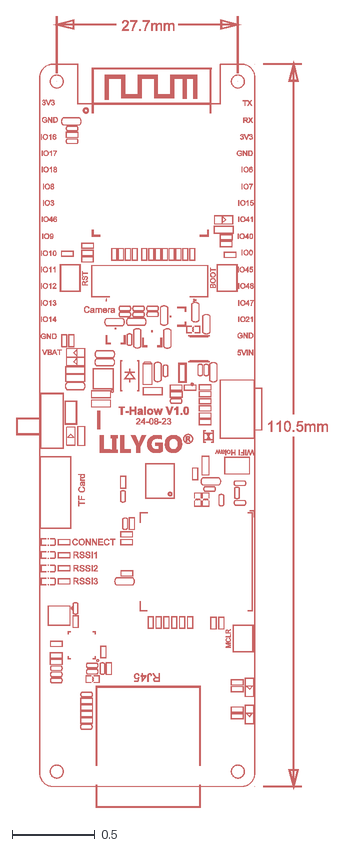
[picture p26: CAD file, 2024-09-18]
hardware/T-Halow V1.0 - TOP.dxf
1.88 x 4.77

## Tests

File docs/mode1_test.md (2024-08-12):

# Mode1: ESP32 and TX-AH test

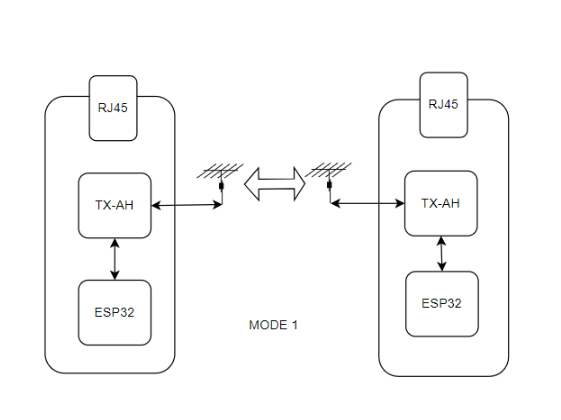
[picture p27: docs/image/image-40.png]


Download usb firmware `huge-ic-ah_xxxxxxxxx_TAIXIN-usb.bin` to Flash, Note that the firmware ends in `-usb.bin`;

https://github.com/Xinyuan-LilyGO/T-Halow/tree/master/firmware

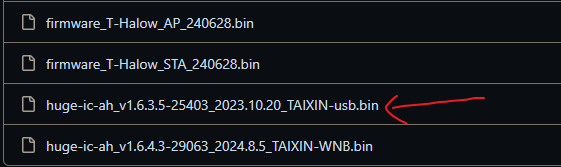
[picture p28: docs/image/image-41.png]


If Flash does not have the firmware, you can download firmware to Flash in either [Method 1](Firmware_burn_1.md) or [Method 2](Firmware_burn_2.md);

After downloading, place the Flash chip on the T-Halow seat;
Note the dot of the flash chip and the arrow on the T-Halow seat son against it;

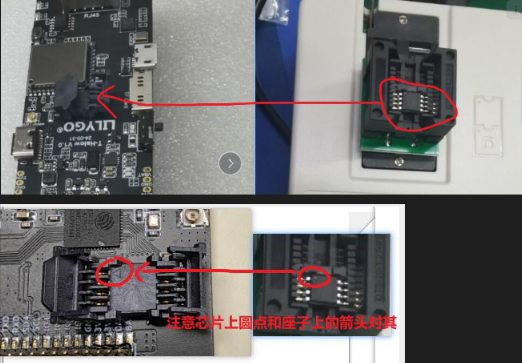
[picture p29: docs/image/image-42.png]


If there are two T-Halow boards with the same frequency of TX-AH module, one can download the esp32 AP firmware and the other can download the esp32 STA firmware through Type-C download;

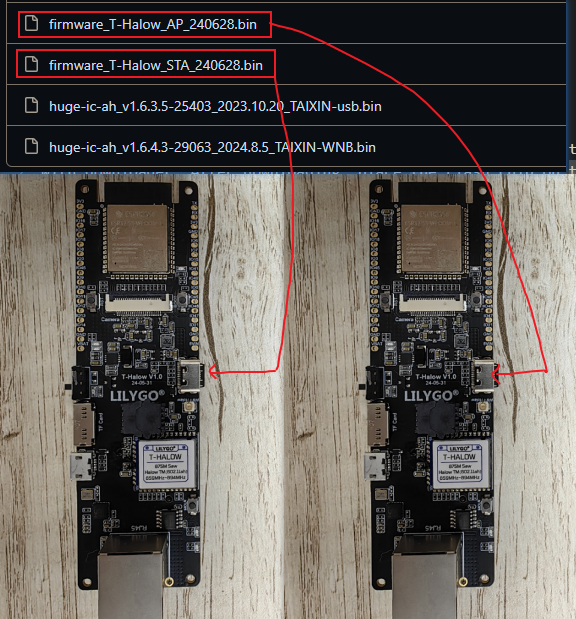
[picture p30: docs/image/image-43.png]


Plug the two boards into Type-C and open the serial port; The TX-AH module is successfully initialized;

During the initialization process, esp32 sends several AT instructions to TX-AH: `AT+SYSDBG=LMAC,0`, `AT+BSS_BW=8`, `AT+MODE=AP/STA`; [More AT](AT_cmd.md);

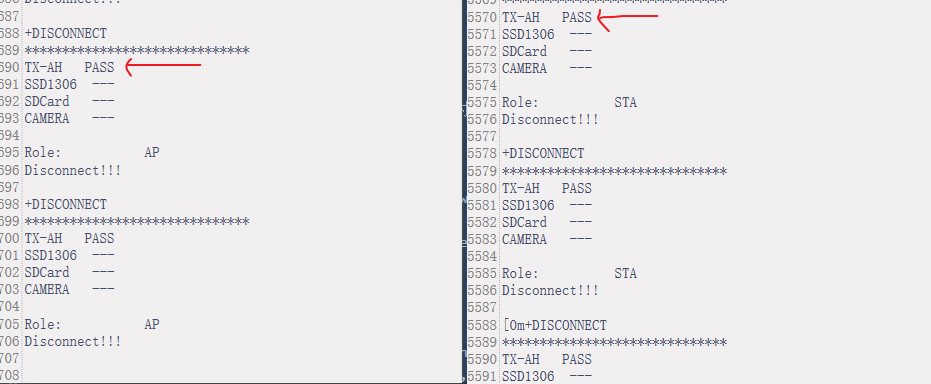
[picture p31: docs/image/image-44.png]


Start pairing, send pairing command; Send the `AT+PAIR=1` pairing command AT the same time. Wait for 3 to 5s. After the pairing succeeds, send the `AT+PAIR=0` command to cancel the pairing.

Print the test sending and receiving data after successful pairing;

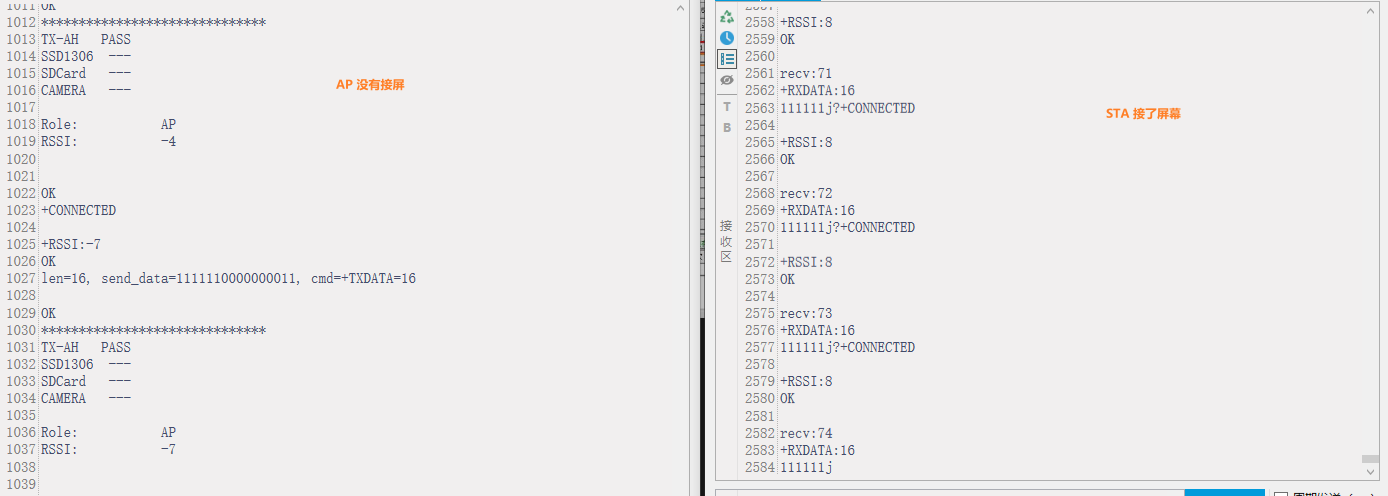
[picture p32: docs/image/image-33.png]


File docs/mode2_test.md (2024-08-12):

# Mode2: TX-AH network bridge

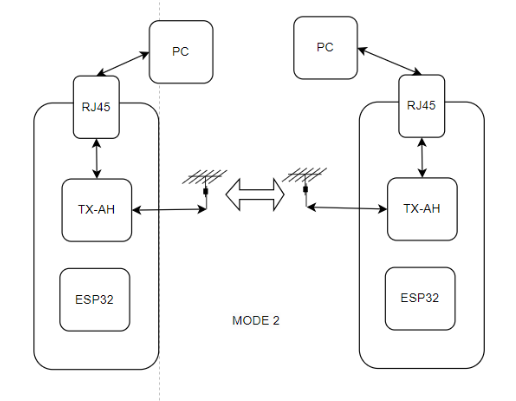
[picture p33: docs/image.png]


## 1. Network bridge firmware download

Download usb firmware `huge-ic-ah_xxxxxxxxx_TAIXIN-WNB.bin` to Flash, 
Note that the firmware ends in `-WNB.bin`;

https://github.com/Xinyuan-LilyGO/T-Halow/tree/master/firmware

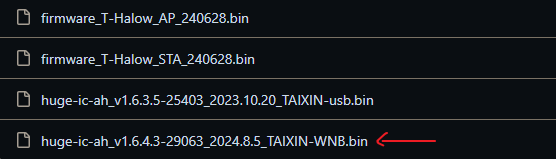
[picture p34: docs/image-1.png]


After downloading, place the Flash chip on the T-Halow seat;

You can wire them as follows:
1. Type-C : Used to supply power to the device
2. Micro-usb: Connect the TX-AH module for debugging
3. RJ45: Connect your computer with an Internet cable

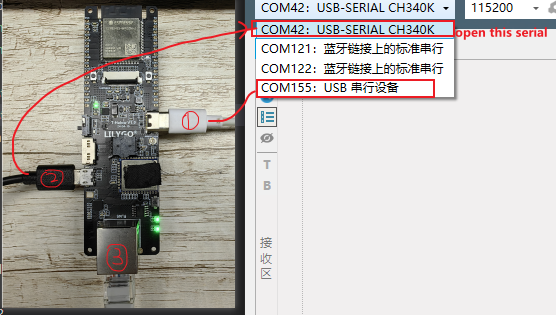
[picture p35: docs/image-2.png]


Then open the serial port of the Micro-usb (serial port suffix CH340); 
Send the [AT command](./AT_cmd.md) for configuration; 

## 2. Wireless network bridge function

### 2.1 Ethernet Settings

Prepare two T-halows to connect to the computer with a network cable. Configure wired network ip addresses for both computers.

Open `Control Panel \ Network and Internet\ Network and Sharing Center` Click Ethernet as shown below

Configure the IP address of the cable network. For example, set the IP address to `10.10.10.123` on one PC

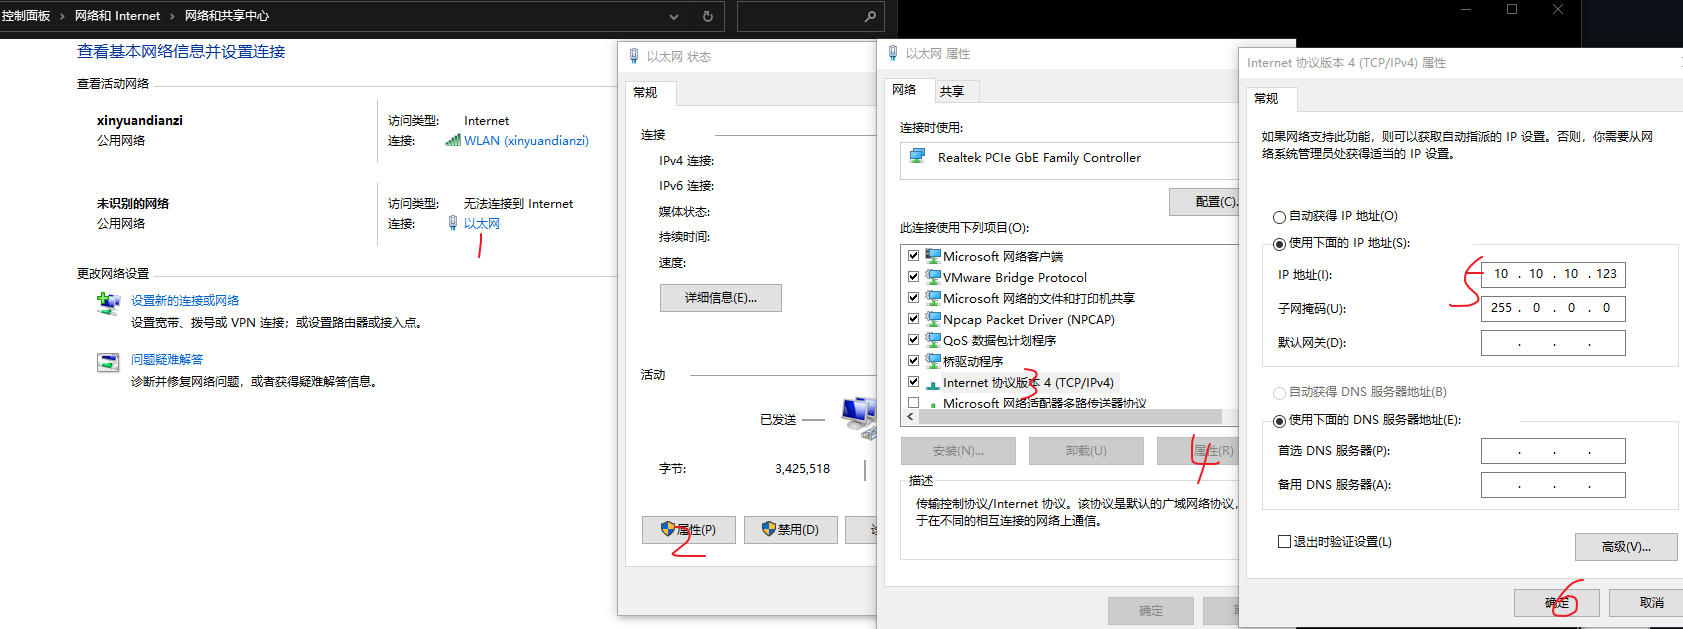
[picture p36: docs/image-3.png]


Set the IP address of the other PC to `10.10.10.156`



Disable the firewall temporarily

The following only describes the method of closing the firewall of windows. For the firewall of other security software, please find the method of closing:

1. `win+r` to bring up the running screen, enter cmd, and press Enter
2. In the cmd window that is displayed, enter `Firewall.cpl` and press Enter
3. In the firewall page that pops up, click "Enable or disable Windows Defender Firewall" options



In the pop-up "Custom Settings" page, select the "Turn off Windows Defender Firewall" option for all, and then click OK



### 2.2 The TX-AH module is paired

Open the serial port (with the CH340 symbol) of the Micro-usb;

Run the `AT+WNBCFG` command to view the configuration of the TX-AH module; Set one module to AP and the other to STA, `bss_bw` and `chan_list` are set to the same;





Start pairing, send pairing command; Send the `AT+PAIR=1` pairing command AT the same time. Wait for pairing success!;



After the pairing succeeds, send the `AT+PAIR=0` command to cancel the pairing.

Then send the `AT+CONN_STATE` command to view, If "+CONNECTED" appears, the pairing is successful;



After the connection is successful, press `win+r`, enter `cmd` to develop the command line window, and then ping each other;



### 2.3 Send and receive data

Development of serial tools, a device set to server



The other device is set to client



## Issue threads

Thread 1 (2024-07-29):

Initial Setup

alphafox02, 2024-07-29:
Good day. I received the T-Halow units today, but I have a few questions after looking over your site.

When I plug in via USBC on a Linux PC I can see the ttyACM0 and go there to see stats about the state of the various interfaces followed by disconnect, this repeats as long as I'm connected.

It then seems like I need to load a TX firmware to the Halow radio, it mentions doing so by running various AT commands, but doesn't fully explain the process. If the T-Halow is plugged into internet is it able to go out and grab firmware? Does the firmware need to be downloaded on the PC and then somehow be put over onto the T-Halow? Do I need the programmer it talks about in the README?

I tried attaching a microUSB cable when opens the ttyUSB0 interface, but it to seems read only with details spitting out every so often.

I'm just looking to set one up as a AP and one as a STA.

Thank you.

irongiant33, 2024-07-29:
confirm I'm experiencing the same issue.

Below is the serial output from what I only assume is the ESP32-S3, connected via USB-C. This process repeats indefinitely as long as the device is connected.

```
[  3114][I][esp32-hal-i2c.c:75] i2cInit(): Initialising I2C Master: sda=7 scl=6 freq=100000
OLED FeatherWing test
E (3040) camera: Camera probe failed with error 0x105(ESP_ERR_NOT_FOUND)
Camera init failed with error 0x105[  3149][W][sd_diskio.cpp:174] sdCommand(): no token received
[  3250][W][sd_diskio.cpp:174] sdCommand(): no token received
[  3350][W][sd_diskio.cpp:174] sdCommand(): no token received
[  3450][E][sd_diskio.cpp:199] sdCommand(): Card Failed! cmd: 0x00
[  3450][W][sd_diskio.cpp:516] ff_sd_initialize(): GO_IDLE_STATE failed
[  3451][E][sd_diskio.cpp:802] sdcard_mount(): f_mount failed: (3) The physical drive cannot work
[  3460][W][sd_diskio.cpp:174] sdCommand(): no token received
[  3565][W][sd_diskio.cpp:174] sdCommand(): no token received
[  3666][W][sd_diskio.cpp:174] sdCommand(): no token received
[  3767][E][sd_diskio.cpp:199] sdCommand(): Card Failed! cmd: 0x00
Card Mount Failed
OK
AT+SYSDBG SUCCEED

OK
AT+BSS_BW SUCCEED

OK
AT+MODE=STA SUCCEED
******************************
TX-AH   PASS
SSD1306  ---
SDCard   ---
CAMERA   ---

Role:          STA
Disconnect!!!

+DISCONNECT
******************************
TX-AH   PASS
SSD1306  ---
SDCard   ---
CAMERA   ---

Role:          STA
Disconnect!!!

[271196]send assoc request to 1e:05:59:63:77:78, ssid= (freq:9240)
[271457]send assoc request to 1e:05:59:63:77:78, ssid= (freq:9080)
[271673]send assoc request to 1e:05:59:63:77:78, ssid= (freq:9080)
[273550]send assoc request to 1e:05:59:63:77:78, ssid= (freq:9160)
+DISCONNECT
******************************
TX-AH   PASS
SSD1306  ---
SDCard   ---
CAMERA   ---

Role:          STA
Disconnect!!!

[274555]send assoc request to 1e:05:59:63:77:78, ssid= (freq:9160)
[276189]send assoc request to 1e:05:59:63:77:78, ssid= (freq:9240)
+DISCONNECT
******************************
```

I am unable to send any serial commands over this interface.

When I connect to the T-HaLow chip via micro-USB, I see a USB interface pop up. I can connect to it, but there is no log output like there is for the ESP32 and I also cannot send any information to the device over serial.

Lastly, I tried connecting an ethernet cable to see if I get an IP address, but I am not assigned one via DHCP. Do I need to statically assign an IP address in order to communicate with the T-HaLow?

alphafox02, 2024-07-29:
On the micro USB I get output showing statistics and info, I’ll have to look again though. On the USBC connection I don’t recall ever seeing a pass next to the TX-AH, but I’ve also not switched out the chip in the T HaLow holder with the one in the bag. It’s not clear to me if it’s flashed yet or not and/or how to flash the AP vs STA firmware.

irongiant33, 2024-07-29:
Furthermore, does the 32MBit serial flash SS package [Winbond 25Q32JVSIQ](https://www.winbond.com/hq/product/code-storage-flash-memory/serial-nor-flash/?__locale=en&partNo=W25Q32JV) provide memory for the T-HaLow, the ESP32 or both? I thought ESP32s came with their own native flash, in the case of the S3, 8MB of it. I used the following command to read & store a flash backup in case I mess things up later:

```
python3 esptool.py --chip esp32s3 --port /dev/ttyACM0 --baud 115200 read_flash 0 0x800000 thalow-flash-contents.bin
```

Then I tried to flash the AP firmware to the ESP32 because it ships with the STA by default. Since I have 2x T-HaLows, I thought maybe since having one as the AP and one as the STA, it might encourage a connection. I used [esptool](https://github.com/espressif/esptool) for this and downloaded the firmware from this repository.

```
python3 esptool.py --chip esp32s3 --port /dev/ttyACM0 --baud 115200 write_flash 0 ~/Downloads/firmware_T-Halow_AP_240628.bin
```

I confirmed that the mode was changed to AP, but there was still no apparent packet connections or exchange between my two devices.

```
[  3114][I][esp32-hal-i2c.c:75] i2cInit(): Initialising I2C Master: sda=7 scl=6 freq=100000
OLED FeatherWing test
E (3040) camera: Camera probe failed with error 0x105(ESP_ERR_NOT_FOUND)
Camera init failed with error 0x105[  3149][W][sd_diskio.cpp:174] sdCommand(): no token received
[  3250][W][sd_diskio.cpp:174] sdCommand(): no token received
[  3350][W][sd_diskio.cpp:174] sdCommand(): no token received
[  3449][E][sd_diskio.cpp:199] sdCommand(): Card Failed! cmd: 0x00
[  3450][W][sd_diskio.cpp:516] ff_sd_initialize(): GO_IDLE_STATE failed
[  3451][E][sd_diskio.cpp:802] sdcard_mount(): f_mount failed: (3) The physical drive cannot work
[  3460][W][sd_diskio.cpp:174] sdCommand(): no token received
[  3565][W][sd_diskio.cpp:174] sdCommand(): no token received
[  3666][W][sd_diskio.cpp:174] sdCommand(): no token received
[  3767][E][sd_diskio.cpp:199] sdCommand(): Card Failed! cmd: 0x00
Card Mount Failed
OK
AT+SYSDBG SUCCEED

OK
AT+BSS_BW SUCCEED

OK
AT+MODE=AP SUCCEED
******************************
TX-AH   PASS
SSD1306  ---
SDCard   ---
CAMERA   ---

Role:           AP
Disconnect!!!

+DISCONNECT
******************************
TX-AH   PASS
SSD1306  ---
SDCard   ---
CAMERA   ---

Role:           AP
Disconnect!!!

+DISCONNECT
******************************
TX-AH   PASS
SSD1306  ---
SDCard   ---
CAMERA   ---

Role:           AP
Disconnect!!!

+DISCONNECT
******************************
```

irongiant33, 2024-07-29:
Lastly, after connecting the TF card there is no longer a verbose output like above. I connected a SSD1306 to 3V3, GND, SCL to pin 6 and SDA to pin 7. I did not get a "PASS" next to the SSD1306 on the debug log, nor did I see any information displayed on the screen. I thought this was the correct place to put the SSD1306?

alphafox02, 2024-07-30:
After using the one application in the README to send commands and sync, I have one node in AP mode and one in STA with a connection between the two.

I have no idea what the chip in each by default did. But it seems like the flash chip in the bag must have been programmed at the factory with the bin file because it’s not until after inserting it that the halow radio becomes usable.
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
alphafox02, 2024-08-27:
I’m still waiting on my replacement chips to enable WB mode, but good to hear it’s working for you. I suspect or at least hope maybe future hardware and software revisions will address what you’ve said. I’ve been making suggestions to them as well.

I’m mainly wanting to plug in a PC on one and reach box plugged in remote on another. Being able to push button pair and/or have a web interface to configure some basic settings would be extremely useful.

alphafox02, 2024-08-29:
New chips arrived. Network bridge mode is now alive! I’ll share more details when it’s not so late.

Humancell, 2024-09-13:
Hello!  Thank you for all of the experimentation that you have done so far!  I'm trying to understand the various documentation and how the default board is configured.

1. When shipped, is the default configuration Mode 1 or Mode 2?  I am guessing Mode 1 since the default ESP32 sketch (TX_AH_Rx00p_STA.ino) seems to be running.
2. The USB-C port () is then connected to the ESP32.  Has anyone reprogrammed the ESP32 successfully at this point?
3. The Micro-USB appears to be connected to the HaLow module, and there is output from the various commands being sent to it by the ESP32.  BUT ... this does not appear to be correct since I am not seeing the AT Commands in this output.  So it could be that echo is turned off?

I have a HaLow access point that is up and running - one I built from a Newracom dev kit - and it's set with a SSID and Password.  What I want to do is simply get an AT Command passthrough to the T-HaLow going so that I can attempt to directly control the HaLow module on the T-HaLow to scan for and hopefuly connect to my AP.

At that point I'd be trying to create a ESP32 library to see if I can perform an HTTP POST from the T-HaLow through the Newracom AP to my cloud server.

Thoughts/Feedback/Suggestions?

Humancell, 2024-09-13:
Some updates to my testing.  When connected to the Micro-USB I am able to send the various AT Commands to the Tianxin HaLow module and they are being handled, even while the ESP32 code is running.

I was able to change the SSID and Password and can see the changes reflected in the output.

08:18:07.365 -> [1893508] [31msend assoc request to ff:ff:ff:ff:ff:ff, ssid=Wovyn-HaLow (freq:9080)
08:18:07.365 ->  [0m[1894400] [31msend assoc request to ff:ff:ff:ff:ff:ff, ssid=Wovyn-HaLow (freq:9160)
08:18:08.299 ->  [0m[1894849] [31msend assoc request to ff:ff:ff:ff:ff:ff, ssid=Wovyn-HaLow (freq:9160)
08:18:08.707 ->  [0m[1895754] [31msend assoc request to ff:ff:ff:ff:ff:ff, ssid=Wovyn-HaLow (freq:9240)
08:18:09.615 ->  [0m[1897484] [31msend assoc request to ff:ff:ff:ff:ff:ff, ssid=Wovyn-HaLow (freq:9240)
08:18:11.374 ->  [0m[1897540] [31msend assoc request to ff:ff:ff:ff:ff:ff, ssid=Wovyn-HaLow (freq:9080)

I have not been able to get a successful association yet and am exploring the other parameters.

Also, for anyone else wanting the AT Commands in English I did a quick Google translation.  :-)
[English Translation - Taixin AH Module AT instruction development guide_20230524100503.pdf](https://github.com/user-attachments/files/16995204/English.Translation.-.Taixin.AH.Module.AT.instruction.development.guide_20230524100503.pdf)

WifiHero91, 2024-09-14:
> New chips arrived. Network bridge mode is now alive! I’ll share more details when it’s not so late.

Hello! I'm in the same shoe as You! How i can ask for new chips?

Thank you!

alphafox02, 2024-09-14:
I have a few extra I can send you, otherwise Lilygo will probably help you out.

WifiHero91, 2024-09-14:
@alphafox02 You are very kind! Lilygo has to fix this (i hope) :)

Humancell, 2024-09-16:
> I have a few extra I can send you, otherwise Lilygo will probably help you out.

If I have a programmer, is the code available somewhere for programming myself?

alphafox02, 2024-09-16:
The guides LilyGO provide point you to the latest Wireless Bridge firmware and steps to flash, although I think the more recent directions show methods of temporarily soldiering the chips on to another device for flashing. If you look back at the commits and go to earlier ones it shows how to use a programmer. I’ve not seen anyone pop in here saying they managed to get chips flashed by a programmer though.

abu-matterize, 2024-10-23:
Hi. I'm facing the similar issue, regarding the setup. I've powered it, seeing solid green light. But failing in responding to the `AT` commands when using microUSB port to communicate.

abu-matterize,
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

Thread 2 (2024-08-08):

Taixin serial port change

aliosa27, 2024-08-08:
Hi! So I was porting my web gui for taixin stuff over to the t-halow, however as you mention, if your using the WNB firmware, its serial port switches to IOA12/13 so the esp32 can not talk to it anymore. This is not ideal. Can you request a custom build of the WNB firmware that allows you to send an at command to switch between IOA12/13 and IOA 10/11? this way at commands can be sent with BOTH taixin firmware's making this far more useable.

aliosa27, 2024-08-08:
closing, I can make this change with the sdk they provide.

Closed 2024-08-08.

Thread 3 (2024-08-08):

Version 2 design change

aliosa27, 2024-08-08:
Because of the way the device handles its serial pins in wnb mode and usb mode, it means that without a hardware toggle, you can’t use the esp32 to end commands if in wnb mode, which is silly. Adding a toggle to switch between serial ports on the taxin chip and pins 5/6 of the esp32 is much more ideal. IOA12/13 mapping to  esp32 5-6 when not in  Ethernet  mode and IOA 10/11 mapping to 5/6 when in Ethernet mode with a switch . Both would facilitate hr ability to control the chip from the esp32.

aliosa27, 2024-08-08:
Another thought is to include a two port Ethernet switch chip, connecting one interface internally to a phy that’s connected to the esp32 and the second to a physical Ethernet interface, allowing the taixin to be controlled over the network from the esp32.

Closed 2024-10-31.

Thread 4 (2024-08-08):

Antenna mount design stl

aliosa27, 2024-08-08:
In some photos I notice you have a 3d printed antenna mount. Can you share the stl for that?

Closed 2024-10-31.

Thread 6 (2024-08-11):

Windows driver for USB 2.0 device

x893, 2024-08-11:
Hello,
I write firemware huge-ic-ah_v1.6.3.5-25403_2023.10.20_TAIXIN-usb.bin to module.
After connect To microUSB **J3** not data to/from terminal.
But if I connect IOA12/IOA13 to USB-DP/USB-DM, I see device USB 2.0 in windows device manager.
Only I can't find deriver for it. VID A012/ PID 4002
Can you help me with driver ?

Thanks in advance
Mitek

aliosa27, 2024-08-12:
no windows driver, but it works with the linux driver on the taixin download page

x893, 2024-08-16:
> no windows driver, but it works with the linux driver on the taixin download page

Thanks. You means
huge-ic-fmac-linux-driver-v2.2.1-26364 ?

Closed 2024-10-31.

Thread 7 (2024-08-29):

Using as Bridge with 3rd party HaLow AP, Scan results in ERROR

jrigling, 2024-08-29:
I intend to use the T-Halow as a network Bridge (HaLow to Ethernet) for connecting non-HaLow devices to a HaLow network. This is like Mode 2 in the documentation, except the AP is NOT a T-HaLow device. The AP uses a Newracom chipset. The AP has been tested with another independent device, using a MorseMicro chipset.

This strategy will not use the AT+PAIR= behavior since it will be using an SSID.

The ESP32 is not used in this configuration.

The AP is configured with
BSS_BW=4MHz
Frequency=910MHz
SSID=Wi-Fi
WIFI_PSK=none

The logs below are from firmware `huge-ic-ah_v1.6.4.3-29063_2024.8.16_.bin`

```
LMAC STATUS:
local: 4a:06:59:86:b2:b8 AID= 0
freq= 910.0 bw=4 chn=3 bgr=-60 iq=0:50:-1:0 dc=0:0(28:50) tx=*5 dly=72:0:0 sif:rsp=0:0(0)
chn:  910.0
bgr:    -60
buf: free=78 tq=0 sq=0 ac=0:0:0:0 agg=0:0:0:0 statq=0 rxq=0:0 skb=0:0 rxb=120K
irq: ac=9 bkn=0 bo(rts:frm)=0:0:0:0:9 to(rts:frm)=0:0 rx=45
tx : cnt=9 dly=0:0ms mcast(bw:mcs)=2:0 agg=1(5994,9:0) data=1KB(1kbps) dur=6ms cca=53 per=0% est_rate=1300kbps fail=0 drop=0
rx : cnt=20 bus=1ms cts_bm=0:0 pks=20 data=3KB(4kbps) dur= 7ms err(phy:fcs)=0:0 ecode=0x0 rssie= 0:0 cache_rxq= 0:0
dbg: dtmd=0:0:0 stamap=0x0 sleepmap=0x0 flag=0x0 rxdp=0 kerr=0 mic=0 lerr=0 kick=0 csc=0 rst=2 ovf=0 nob=0 tsnr=0 rssi=0 rxdut=0% txp=0 rxg=5
cca: 4s st12= 41:0 mid1224= 50:44:0:0 ed1224= 50:18:0:0 ch_bz= 0
chip-temperature:44, vcc:3.26, vdd13b:1.31, vdd13c:1.31
sta_list: no sta
[2463184]send assoc request to ff:ff:ff:ff:ff:ff, ssid=Wi-Fi (freq:9100)
[2463734]send assoc request to ff:ff:ff:ff:ff:ff, ssid=Wi-Fi (freq:9100)
[2463761]send assoc request to ff:ff:ff:ff:ff:ff, ssid=Wi-Fi (freq:9100)
```

After setting the BSS_BW and SSID with AT commands, the logs start to include attempts to associate, but the address is `FF:FF:FF:FF:FF:FF`, which doesn't match the AP. Is this expected?

I also changed the channel list with `AT+CHAN_LIST=9100` and the PSK with `AT+KEYMGMT=NONE` to match the 3rd party AP configuration.

I try to request `AT+SCAN_AP` so I can then `AT+BSSLIST?` and see if the AP is discovered. The `AT+SCAN_AP` returns `ERROR`

What should I do to understand why the AP SCAN results in an error?  Is this causing the STA to not find the AP?

aliosa27, 2024-08-30:
the scan command seem to be broken on the AT firmware. I have also noticed that trying to associate to a newracom device fails, while newracom -> morse works. The halow stack seems to be a little different here. I think you might have to reach out directly to taixin.

Humancell, 2024-10-16:
Yes ... adding to this ... I have tried to test extensively getting these Lilygo/Taixin devices working with certified 802.11ah Newracom and Morse Micro devices and they do NOT work.

I have reached out to Taixin numerous times asking for assistance, and have got no reply.

https://en.taixin-semi.com/Product?prouctSubClass=33

From what I can tell, their chipset or firmware are NOT 802.11ah compliant.  :-(

This one module is listed on the WiFI Alliance website as being certified ... but maybe not the one on this product?

Product Name: IEEE802.11ah Halow Wireless Module
Model Number: TXW8301
Total Variants: 1 (1 result)
Brand: Taixin Semiconductor Co., Ltd.
Category: Other
Last Certified Date: 2024-04-26

Closed 2024-11-30.

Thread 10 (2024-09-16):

Bridge mode not working

WifiHero91, 2024-09-16:
Dear Lilygo!

I got the two T-halow but in bridge mode it is not working. They connected state got by AT+CONN_STATE command but none of a packet go trought the bridge. I read some other buyer has the same issue and they got now chips what solved the problem.

Please send me the right chips.

mail@vargaimre.hu
order number: LILYGO-25417

Thank you!
Kind Regards,
Imre Varga

WifiHero91, 2024-10-16:
It is still problem. I bought product what is not working and Lilygo support doesnt want to solve it.

ShallowGreen123, 2024-10-17:
You can try sending `AT+LOADDEF=1` to reset each T-Halow, and then try it again in your own way;

Note that after assigning the address, ping the address of the `Ethernet adapter Ethernet` network segment

WifiHero91, 2024-10-18:
What is Ethernet adapter Ethernet network segment?  Do i need to ping my ethernet interface address? It doesn't matter because BROADCAST messages doesn't go over the WB. For Broadcast messages you dont need the ARP table.....
Please send new flash like alphafox02 with the right WB version!

ShallowGreen123, 2024-10-21:
You can try to use `AT+VERSION=?` to check the firmware version of the TX-AH module. The firmware in bridge mode is `VERSION:v1.6.4.3-xxxxx`.

If it is another version, please replace the firmware chip that comes with lilygo;

If there is no `VERSION:v1.6.4.3-xxxxx` firmware chip, you can ask after-sales service to send you a replacement one.

WifiHero91, 2024-10-21:
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

Thank You! The version is different!

WifiHero91, 2024-10-21:
@ShallowGreen123  What is email address where I can ask for new flash?

ShallowGreen123, 2024-10-22:
It seems that the firmware version is wrong if it doesn't work;

There should be a flash chip in the product package, just replace it; here is a demonstration video:
https://www.youtube.com/watch?v=nM2GE8Imshc

If there is indeed no flash in the product package, contact after-sales service to reissue it; or after seeing this reply, confirm that there is no flash in the product package, I can also help feedback;

WifiHero91, 2024-10-22:
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
I changed to the other flash in the zip lock bag and also got different version.

ShallowGreen123, 2024-10-22:
It seems that I did not send you the correct bridge firmware, you can give feedback to the after-sales

WifiHero91, 2024-10-31:
I send feedback and hope the new flash will be arrive soon.

WifiHero91, 2024-11-18:
I got the flash but i think they are completly empty. The output.:

[  3114][I][esp32-hal-i2c.c:75] i2cInit(): Initialising I2C Master: sda=7 scl=6 freq=100000
OLED FeatherWing test
E (3040) camera: Camera probe failed with error 0x105(ESP_ERR_NOT_FOUND)
Camera init failed with error 0x105[  3149][W][sd_diskio.cpp:174] sdCommand(): no token received
[  3250][W][sd_diskio.cpp:174] sdCommand(): no token received
[  3350][W][sd_diskio.cpp:174] sdCommand(): no token received
[  3450][E][sd_diskio.cpp:199] sdCommand(): Card Failed! cmd: 0x00
[  3450][W][sd_diskio.cpp:516] ff_sd_initialize(): GO_IDLE_STATE failed
[  3451][E][sd_diskio.cpp:802] sdcard_mount(): f_mount failed: (3) The physical drive cannot work
[  3460][W][sd_diskio.cpp:174] sdCommand(): no token received
[  3565][W][sd_diskio.cpp:174] sdCommand(): no token received
[  3666][W][sd_diskio.cpp:174] sdCommand(): no token received
[  3767][E][sd_diskio.cpp:199] sdCommand(): Card Failed! cmd: 0x00
Card Mount Failed
AT+SYSDBG ERROR
AT+BSS_BW FAILD
AT+MODE=STA FAILD
******************************
TX-AH    ---
SSD1306  ---
SDCard   ---
CAMERA   ---

Role:          STA
Disconnect!!!
******************************
TX-AH    ---
SSD1306  ---
SDCard   ---
CAMERA   ---

Role:          STA
Disconnect!!!

WifiHero91, 2024-11-18:
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
 That was written on the zip lock bag.

WifiHero91, 2024-12-06:
I got two new flash from Lilygo with the bridge mode and start to work as it has to.

Closed 2024-12-06.

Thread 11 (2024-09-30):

T-Halow setup

nirshem, 2024-09-30:
Hi Lilygo,

I looking for setup of STA connection to AP based on mode1 for transferring video origin from onboard camera on the STA side directly to the AP that connected to PC.

I got some questions raised

1) Is it still mode 1 or its a combination of MODE1 on the STA side and MODE2 on the AP side, is it possible ? if yes how to setup ?

2) I tried to change mode from STA to AP using AT+MODE=AP command but its looks like the role stays STA

3) Why the platform doesn't support burn the flash on its own - there is esp32 on board, why do I need another HW for it ?
Can i wire the Winbond flash chip directly to SPI wires of general ESP32 board and burn it ? if yes how-to ?

Thanks

Closed 2024-11-15.

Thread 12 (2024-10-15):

AP-STA-net-AP-STA and pair button feedback

alphafox02, 2024-10-15:
Just letting you all know, I can confirm that traffic passed between 2 relay nodes. What I mean is that if you laid three distinct pairs down on a table and put an Ethernet cable between device 2 and 3 and between 4 and 5, the traffic will flow from a PC hooked to device one to a PC connected to device 6.

I'm the one testing the drone setup. I believe my initial problem was that I received 4 devices that had already had some configuration done and what I needed to do was to wipe all previous pairings.

As far as the pair buttons - I've only seen two out of four devices light the connect red light when pushing the pair button and I can't be for certain the mode switch is in fact changing the mode. Instead I've been doing it with AT commands.

Duan-GX, 2024-10-16:
Do you mean the following? If so, the data from node 1 can flow to node 6. That is, the two PCs can ping each other.

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

For version 1 of T-Halow, COMMECT's light stays on only after the connection is successful; At other times, the COMMECT blinks when you hold down the PAIR key. If there is no phenomenon when you press the PAIR key for a long time, you can open the serial port to see if there is any information output when the PAIR key is pressed. If not, the PAIR may be broken.

Want to determine if the mode switch is working. You can open the serial port, and then flip the mode switch to see whether the serial port has output (to avoid interference, you can use `AT+SYSDBG=LMAC,0` to turn off the debug message).

Duan-GX, 2024-10-16:
Do you mean the following? If so, the data from node 1 can flow to node 6. That is, the two PCs can ping each other.
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
For version 1 of T-Halow, COMMECT's light stays on only after the connection is successful; At other times, the COMMECT blinks when you hold down the PAIR key. If there is no phenomenon when you press the PAIR key for a long time, you can open the serial port to see if there is any information output when the PAIR key is pressed. If not, the PAIR may be broken.

Want to determine if the mode switch is working. You can open the serial port, and then flip the mode switch to see whether the serial port has output (to avoid interference, you can use `AT+SYSDBG=LMAC,0` to turn off the debug message).

alphafox02, 2024-10-16:
Yes, the diagram works as you show.

For pairing. Only two out of the four I have (version 1) light the connect light when pushing the pair button.

I’ll investigate further. I ended up using AT commands to set mode and conduct pair. I’ll check via serial again and see if switch is changing mode.

I do have one situation where I have an old model and a new model paired. When I turn them off and back on the pair is not successful until I reboot the newer model by pushing the button close to the Ethernet port if I recall (some kind of reboot) and almost immediately it comes back on and link is successful confirmed with rssi lights and connect all being lit.

I will update ticket with findings, but so far besides the few things I mention, it’s working well.

alphafox02, 2024-10-19:
What commands would you suggest running in order to put each pair on say 4Mhz wide bandwidth and 3 unique frequencies/channels?

I’m first going to repair my 6 units into groups according to old hardware and new hardware. I have two out of 3 pairs mix matched. I’d like to see if that helps resolve some of my intermittent connection issues and if not I’ll try the bandwidth and channel change.

alphafox02, 2024-10-19:
After paying closer attention while testing again today I've found that out of the four new style T-Halow's I have, 1 is an AP and 3 are a STA when dealing with bridge mode. Regardless of the switch position or AT commands, the mode will not change. What will happen is if I boot one up after changing it from STA to AP via AT+MODE=AP, upon reboot it'll revert to STA confirmed by checking serial output AT+WNBCFG. If I push the button beside the ethernet port to trigger a reboot, it will in fact change modes and only stay in the mode I want it to be in until another power cycle.

That probably sounds confusing, but it's what I'm observing. So to proceed with my test I used 5x T-Halow devices. I pair an old one set to STA mode to the one new unit that was shipped to me in AP mode. I then used an old one and put it into AP mode and used two other new devices in STA mode to connect to it. This still allowed me to test a connection across two drones by having only one drone use the ethernet between devices.

However, there's still an issue sometimes where all devices will be connected, yet a ping will not go across. Even if I bring all the devices back close together. I'll have to power cycle everything and then suddenly the ping will work perfectly fine for some time.

alphafox02, 2024-10-22:
I just noticed though that the pair button seems to have no effect, connect light doesn't light, and while observing via console connection there's no sign on the AP that it's going to pair mode. I'll flash my other three and manually put them in pair mode and continue testing.

Closed 2024-10-23.

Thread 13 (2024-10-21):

Using LilyGo T-Halow - ESP32 Wireless Network instead of Ethernet Network

f2ka07, 2024-10-21:
I recently acquired two T-Halow modules and configured IP addresses through the Ethernet bridge. However, when I disconnect the Ethernet cable, they lose connectivity.  This is expected, but can we connect the T-Halow devices to a wireless network instead of an Ethernet one?  For instance, can T-Halow get wireless LAN connectivity from ESP32?

ShallowGreen123, 2024-10-22:
You can try to use `AT+VERSION=?` to check the firmware version of the TX-AH module. The firmware in bridge mode is `VERSION:v1.6.4.3-xxxxx`. If it is another version, please replace the firmware chip that comes with lilygo to see if it can help you solve the problem.

here is a demonstration video:
[https://www.youtube.com/watch?v=nM2GE8Imshc](https://www.youtube.com/watch?v=nM2GE8Imshc)

f2ka07, 2024-10-23:
I got stuck because I encountered another issue with one of the T-Halow devices.   It doesn't respond to the AT command. The only output it gives is as below. Sometimes the output comes from USB C and other times in the other USB. What could be the issue?

ESP-ROM:esp32s3-20210327
OLED FeatherWing test
Camera init failed with error 0x105Card Mount Failed
AT+SYSDBG ERROR
AT+BSS_BW FAILD
AT+MODE=STA FAILD
******************************
TX-AH    ---
SSD1306  ---
SDCard   ---
CAMERA   ---

Role:          STA
Disconnect!!!
******************************
TX-AH    ---
SSD1306  ---
SDCard   ---
CAMERA   ---

Role:          STA
Disconnect!!!
******************************
TX-AH    ---
SSD1306  ---
SDCard   ---
CAMERA   ---

Role:          STA
Disconnect!!!

Closed 2024-12-07.

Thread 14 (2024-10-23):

Flash chip comes pre-flashed with firmware?

abu-matterize, 2024-10-23:
Hello there,

I brought T-Halow and tried to communicate with TX-AH module via AT commands with microUSB port. But failed.

Do I need to flash the firmware to do so? Or is there a way I can communicate via ESP32 out of the box?

abu-matterize, 2024-10-23:
After USB-C is plugged - Solid green light. Opening JTAG port with 115200 prints,
```bash
[369424]send assoc request to 22:9f:f1:a2:8d:28, ssid= (freq:8660)
+DISCONNECT
******************************
TX-AH   PASS
SSD1306  ---
SDCard   ---
CAMERA   ---

Role:          STA
Disconnect!!!

[372870]send assoc request to 22:9f:f1:a2:8d:28, ssid= (freq:8660)
[373232]send assoc request to 22:9f:f1:a2:8d:28, ssid= (freq:8660)
[374714]send assoc request to 22:9f:f1:a2:8d:28, ssid= (freq:8660)
+DISCONNECT
******************************
```

alphafox02, 2024-10-23:
Please refer to this video I put together. Since you’ve mentioned micro usb port I am making the assumption you have the older hardware.

Not all applications open and communicate correctly with the micro usb port which is what you need to connect to for the purposes of sending AT commands. You can likely find the windows version of this application and follow along as needed, but I used Linux.

https://www.youtube.com/watch?v=vZjUTUHTOX4

abu-matterize, 2024-10-23:
The label in the hardware says: `T-Halow V1.0 24-05-31`

abu-matterize, 2024-10-23:
And it's print,
```
cca: 4s st12= 0:0 mid1224= 0:0:0:0 ed1224= 0:0:0:0 ch_bz= 0
chip-temperature:47, vcc:3.30, vdd13b:1.34, vdd13c:1.33
sta_list: no sta
```
every 2 seconds.

alphafox02, 2024-10-23:
Yep, use the chips provided that came in separate bags. I can’t speak to the hardware confidently as you’re mentioning you have a micro usb port. I have two hardware models, the older ones that had micro usb and usbc ports and newer hardware that has just usbc port but also has a mode switch for ap/sta and a pair button.

If you’re now seeing output like you’ve shown above on the micro usb port, you should be able to issue AT commands.

alphafox02, 2024-10-23:
If you’re simply trying to use them to setup a wireless bridge mode, meaning you can plug a laptop into each one and be able to ping from laptop to laptop, then check out the video I shared. You should be able to give AT commands to make one an AP and one a STA and then initiate a pairing process once. Once complete, you’ll be able to communicate across.

If you’re trying to setup one of the other modes, you’ll have to refer to the info lilygo provided. I’ve only focused on bridge mode so far.

abu-matterize, 2024-10-23:
Here it is.
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

abu-matterize, 2024-10-23:
I'm looking to get the `AT` commands working initially.

alphafox02, 2024-10-23:
Yep, I have that version too - just the 900mhz one instead. The video and steps I mention above should assist you assuming there’s no problems with the chips you inserted. Pay super close attention to the markings and dot on them as I accidentally briefly put one in to the seat incorrectly. Since you’re seeing output on micro usb you of course have if in correct.

abu-matterize, 2024-10-23:
I'm using `picocom`, I tried with `serialportassistant` as well, but the results are same.

abu-matterize, 2024-10-23:
I've 2 devices, one replaced flash chip came with bag and another as it's out of box. The log is only printed from the flash swapped device.

alphafox02, 2024-10-23:
Each device should’ve came with a chip in a bag, based on my knowledge of the older devices like you have.

You need to replace the flash chip of each one with the chip in the bag.

Then perform the steps according to lilygo images or my video.

I don’t see in any of your screen shots above where you are issuing AT commands.

abu-matterize, 2024-10-23:
Okay. I replaced flash chips for both devices. Here is the command I've issued and received no response.
```bash
*** local echo: yes ***
AT+MODE?
[62723]
LMAC STATUS:
local: 22:9f:f1:9c:9e:40 AID= 0
freq= 866.0 bw=2 chn=3 bgr=-60 iq=0:50:-1:0 dc=0:0(7:-1) tx=*5 dly=64:0:0 sif:rsp=0:0(0)
chn:  866.0
bgr:    -60
buf: free=78 tq=0 sq=0 ac=0:0:0:0 agg=0:0:0:0 statq=0 rxq=0:0 skb=0:0 rxb=120K
irq: ac=0 bkn=0 bo(rts:frm)=0:0:0:0:0 to(rts:frm)=0:0 rx=15
tx : cnt=0 dly=0:0ms mcast(bw:mcs)=2:0 agg=0(6027,0:0) data=0KB(0kbps) dur=0ms cca=0 per=0% est_rate=0kbps fail=0 drop=0
rx : cnt=15 bus=0ms cts_bm=0:0 pks=15 data=1KB(1kbps) dur= 6ms err(phy:fcs)=0:0 ecode=0x0 rssie= 0:0 cache_rxq= 0:0
dbg: dtmd=0:0:0 stamap=0x0 sleepmap=0x0 flag=0x0 rxdp=0 kerr=0 mic=0 lerr=0 kick=0 csc=0 rst=0 ovf=0 nob=0 tsnr=0 rssi=0 rxdut=0% txp=0 rxg=5
cca: 4s st12= 0:0 mid1224= 0:0:0:0 ed1224= 0:0:0:0 ch_bz= 0
chip-temperature:45, vcc:3.31, vdd13b:1.31, vdd13c:1.31
sta_list: no sta
```

abu-matterize, 2024-10-23:
Okay. Seems like AT command is responding.

alphafox02, 2024-10-23:
Yep that shows you it’s working. If you refer to the video I linked you to it shows you all the steps or issue the commands per the documentation.

For example on 1
AT+MODE=AP

on 2
AP+MODE=STA

on both while leaving both powered
AT+PAIR=1

look for successful pair then on both
AT+PAIR=0

abu-matterize, 2024-10-23:
The behaviour is related to `picocom` it seems. When I copy paste and hit return, `AT` command responds, but when I type it in, no response.

alphafox02, 2024-10-23:
You can then plug one into your home router, for example, and plug your laptop into another. If everything is working, you should get DHCP from your home router.

alphafox02, 2024-10-23:
> The behaviour is related to `picocom` it seems. When I copy paste and hit return, `AT` command responds, but when I type it in, no response.

Interesting, yeah I use what I showed in the video as that worked great for me.

abu-matterize, 2024-10-23:
Alright. It's paired.

```bash
STA0: 22:9f:f1:73:52:40
tx0: mcs=*1 bw=2MHz snr=54 cnt=16 agg=1 data=1KB(2kbps) dur=11ms dut=50% txq=0 cca=102 ack=1KB(16) drop=0KB(0) per= 0%
rx0: mcs=0 bw=2MHz evm(avg:std)=0:0 rssi=-13 agc=0 cnt=27 agg=1 data=1KB(2kbps) dur=11ms dut=49% fcsErr=0, freqDev=-381Hz adv_bw=0:0:0:0
```

abu-matterize, 2024-10-23:
By the way, does it required to append `CR LF` at the end? What's the raw frame looks like?

alphafox02, 2024-10-23:
Not sure, I’ve not used more advanced commands/setup yet.

abu-matterize, 2024-10-23:
Thanks for your help man.

abu-matterize, 2024-10-23:
Interestingly, it's not pasted and hit return. Once pasted - it response back.

abu-matterize, 2024-10-25:
Just a quick question @alphafox02 - Did you managed to work with WiFi STA and AP mode building a bridge instead of the Ethernet connections?

alphafox02, 2024-10-25:
Please explain more.

I was mainly focused on the bridge from AP to STA or STA AP STA and being able to have devices plugged in via Ethernet communicate across. In those configurations things have worked. But in both configurations, the bridge is built across the Halow wireless bridge.

I’ve also tested multiple pairs on drones, but that gets a little more complicated.

abu-matterize, 2024-10-25:
Here is my thought. I'm planning to setup first t-halow (TX-AH) as an AP and the same as an WiFi AP. And the second t-halow (TX-AH) as an STA with WiFi AP.

If I connect first WiFi AP to device 1 and second WiFi AP to device 2 and assign IP address, will I be able to ping each other?

Closed 2024-12-09.

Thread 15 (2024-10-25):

Mixing Mode1 & Mode2

maciejpawel, 2024-10-25:
Is it possible to mix mode1 and mode2?

I want to receive data (not especially internet) via ethernet connection send it via HaLow --> second device receive via HaLow and send it via esp32 WiFi to connect my phone wireless to it.

Due to description there is no chance to such solution...

Thanks!

nirshem, 2024-11-03:
In order to mix two modes its looks like the firmware should support it. the main issue that I noticed on youtube is the limited bandwidth to serial because its looks like Lilygo doesnt put the effort to wire esp32 to Halow with the eth lines in addition to the serial lines. its a really downfall of this product! unless someone will find some hack for it BW is limited

WifiHero91, 2024-12-06:
> In order to mix two modes its looks like the firmware should support it. the main issue that I noticed on youtube is the limited bandwidth to serial because its looks like Lilygo doesnt put the effort to wire esp32 to Halow with the eth lines in addition to the serial lines. its a really downfall of this product! unless someone will find some hack for it BW is limited

This is a very good idea!  @ShallowGreen123 please make a new version!

Closed 2025-01-22.

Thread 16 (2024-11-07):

Unable to establish mode 1

nirshem, 2024-11-07:
I flashed with the bin named "..usb" (mode1) and connected via USB-C - there is no connectivity to the PC. The pc ring up and down like the device is connected and disconnected again and again .

than i tried something else - i pushed the boot button while powering up, than i succeed to establish serial over the USB-C directly to the ESP32 - than succeed to load the bin file of STA.

Now i want the device to work as mode 1 but reboot caused the PC ringing again like the USB-C connected/disconnected , i need it for the AT commands, what your advice in this case ?

thanks

ShallowGreen123, 2024-11-07:
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

1、These two firmwares can only be downloaded to esp32 (green box)

2、These two firmwares are for the TX-AH module and cannot be downloaded to the esp32 (red box)

It is usually downloaded in the package. The default firmware for version 2 is `huge-xxxxx-usb.bin`, and the additional version is `huge-xxxxxx-WNB.bin`;

You can use `AT+VERSION=?` to check the version of the TX-AH module;

`huge-xxxxx-usb.bin`:+VERSION:v1.6.3.5-25403
`huge-xxxxxx-WNB.bin`:+VERSION:v1.6.4.3-29063

----------------
If the problem is not solved, a troubleshooting screen can be provided；

nirshem, 2024-11-07:
Hi,

The mentioned information is known and its exactly what I did to be clarify here are the steps i followed in order to establish MODE 1 (esp32 only):

1) I burned the portable flash (**winbond chip**) with the huge-xxxxx-usb.bin
2) Than i found that the USB-C connected disconnected again and again to the PC
3) I pressed the BOOT button and succeed to establish the serial connectivity (over USB-c) to the ESP32
4) I succeed to burn **the ESP 32** with firmare_T-halow_AP.bin (green box
5) now again after reset the **USB-C ringing again and again** and no debug info in serial

I hope this is more clearly

Thanks

ShallowGreen123, 2024-11-07:
Can you provide a fault video？

Closed 2024-12-23.

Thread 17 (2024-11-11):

How to work wifi camera at 900Mhz band ?

dinosauria123, 2024-11-11:
I tried your CameraWebServer.ino example and I found it can transfer camera image at 2.5GHZ band SSID wifi network.

How can I transfer image at 900 MHz band?

dinosauria123, 2024-11-12:
Sorry, I found CameraWebServer.ino is not for 900MHz band.

I move to  TX_AH_Rx00p_AP.ino but I got

AT+SYSDBG ERROR
AT+BSS_BW FAILD
AT+MODE=AP FAILD

I need to setup flash memory ?

dinosauria123, 2024-11-12:
I use Ubuntu Linux terminal.

AT commands success  /dev/ttyUSB0 (MicroUSB) but fails /dev/ttyACM0 (USB-C).

It seems  sendAT() function to send AT Command via USB-C ?

dinosauria123, 2024-11-12:
I could connect two T-Halow board by input AT command manually.

[208550]wnb: pairing done, save wnb config!

[208553]erase flash, 1 sectors ...

[208618]write flash, 844 bytes ...

[208622]verify flash ... OK

[208623]switch syscfg partition ... OK

[208626]syscfg_write OK! (addr:ff000, crc=68c0, size:844, last_addr:fe000)

[215961]add_sta: aid= 1 6a:9c:00:92:94:78

[215963]wnb: [6a:9c:00:92:94:78] connect success!

But I could not get ping back to another PC.

My flash firmware version is v1.6.3.3-26347.

ShallowGreen123, 2024-11-13:
May I see a picture of your device?

There is a firmware problem with the TX-AH module of your device; If you have a downloader, you can refer to the [documentation](https://github.com/Xinyuan-LilyGO/T-Halow?tab=readme-ov-file#firmware-download) and burn the [firmware of the TX-AH](https://github.com/Xinyuan-LilyGO/T-Halow/tree/master/firmware) module yourself;

If not, I can only give you a return for another, I'm sorry;

dinosauria123, 2024-11-13:
Thank you for your reply !

I could burn firmware huge-ic-ah_v1.6.4.3-29063_2024.8.16_WNB.bin, Now I can ping back to another PC, fine.

I would like transfer image one to another T-Halow board.

It seems mode2 (Bridge mode) is promising because it may access by IP address.
I am looking for the way to set IP address of ESP32 camera within a T-halow network.

Any helps do you have ?

dinosauria123, 2024-11-13:
A picture of my board.
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

I could burn firmware by cheap CH341A board.
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

ShallowGreen123, 2024-11-13:
Well done;

Regarding the setting of ESP32 camera address in T-Halow, the TaiXin official did not provide more detailed chip and image transmission related information;

So I may not be able to help you with that;

dinosauria123, 2024-11-13:
I am very sad to hear this information ( T T )

I hope TaiXin open information and T-Halow can transfer image as easy as M5Camera....

Closed 2024-11-13.

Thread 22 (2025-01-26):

audio to audio

zhjygit, 2025-01-26:
How to use the T-Halow project to implement audio full-duplex calls？
在野外户外条件下，远距离的全双工音频通话。点对点情况下怎么实现呢？如果是sip协议的话，还需要服务器，是不是设备自身无法支撑？有其他的解决方案吗？就是说，不需要ppt这样的按键，能够直接通话，泰心的厂家貌似是有这样的方案，但是不知道怎么实现的

Closed 2025-03-12.

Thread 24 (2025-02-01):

Can you provide a schematic for the version 1 PCB?

wincross7, 2025-02-01:
Can you provide a schematic for the version 1 PCB?
I bought two T-Halow boards in Japan and they were version 1.
I need the schematic for them.

Closed 2025-03-18.

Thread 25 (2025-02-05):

Firmware

IlyaID, 2025-02-05:
Hello, I ran into a problem that when downloading firmware from the repository to a new memory chip with this chip, the board does not respond to AT commands. Is there any suggestion that this is not the case with the firmware or with the download? The download was carried out according to the instructions using the Download firmware via downloader. I only downloaded the firmware hugc-ic-ah-xxxxxxxxxxxx.bin.

Closed 2025-03-22.

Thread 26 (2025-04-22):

WPA version used in TX-AH module

Shidqinfl, 2025-04-22:
Hello,
I'm currently working with the TTGO T-HaLow board which uses the TX-AH module, and I would like to confirm the WPA version supported by this module.

The documentation mentions the use of AT+KEYMGMT=WPA-PSK, but it does not specify whether this refers to WPA1, WPA2, or WPA3.

🟡 Could you please clarify:

What version of WPA does WPA-PSK in AT+KEYMGMT refer to?

Is there any plan to support WPA3 in the future?

Thanks in advance for your help! 🙏

r-hikosaka, 2025-05-09:
Hello, I have a question about T‑HaLow.

To fix an issue where the AP and STA can pair but Ethernet communication doesn’t work, I reflashed both T‑HaLow units with the firmware listed below and pressed the MCLR button. After doing so, no serial output appears, and pairing now succeeds only intermittently. Even when pairing does succeed, Ethernet still fails to communicate.

What should I do?

Written firmware:
https://github.com/Xinyuan-LilyGO/T-Halow/blob/master/examples/AT_test/AT_test.ino

Closed 2025-06-23.

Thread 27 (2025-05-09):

Ethernet communication doesn’t work

r-hikosaka, 2025-05-09:
Hello, I have a question about T‑HaLow.

I’m facing an issue where the T‑HaLow AP and STA can pair successfully, but Ethernet communication doesn’t work. To resolve this, I reflashed both T‑HaLow units with the firmware listed below and pressed the MCLR button. After doing so, no serial output appears, and pairing now succeeds only intermittently. Even when pairing does succeed, Ethernet still fails to communicate.

https://github.com/user-attachments/assets/25cb0cd1-37a5-417d-9285-45e63c3b8305

What should I do?

Written firmware:
https://github.com/Xinyuan-LilyGO/T-Halow/blob/master/examples/AT_test/AT_test.ino

Closed 2025-07-10.

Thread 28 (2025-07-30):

Doubts regarding sending data using AT commands with T-Halow v1 (EU version)

marcatcid, 2025-07-30:
I have two T-Halow boards configured  to behave as  AP and STA connected to a PC where I have a serial terminal emulator. The firmware in the T-Halow board is the one that comes by default.

I have followed the instructions in https://github.com/Xinyuan-LilyGO/T-Halow/blob/master/docs/AT_cmd.md to send
I have successfully sent data from both the AP and the STA when I write the following commands in the serial terminal, as shown in Test 1:
- AT+TXDATA=24
- 111111000000001234567890

However, I try to follow Test 2 to specify the MAC address of the destination it does not work. Neither the AP or the STA receive data. In my case what I write from the AP is this:
- AT+TXDATA=24
- 8259137C9EC88259138a6338303031323334353637383930

It seems that only the "short format" (11111100000000) is working; but in this case; how can I specify the MAC of the receiver when I have different stations?

-

pbetelematica-telbcn, 2025-09-15:
Hi @mmohsinm-1, I did not receive any response but I continued investigating and solved the issue; it was a misunderstanding between ASCII and HEX representations.  I must say, that the documentation was quite confusing for me and I think it would be good to have a clearer explanation of this point, so that people do not need to struggle to make it work.

The main issue is that the data that is transmitted once after the command "AT+TXDATA=24" needs to be the  addresses and the message in HEX.
As I was using a serial terminal, If the message "8259137C9EC88259138a6338303031323334353637383930" is sent "as is" in the terminal, values are interpreted as ASCII chars not has HEX bytes.  So, what needs to be provided in the terminal is the ASCII representation of the hex (for the MACs and for the message); as it is done in  the broadcast example "111111000000001234567890"  However, for the unicast MAC addresses some of the hex values will correspond to non-printing chars; what makes it difficult to provide an ASCII representation. Some serial terminals (not all) allow you to directly provide an HEX string; this would be the easiest approach;  in my case, with YAT, it worked with \h(8259137C9EC88259138a6338303031323334353637383930).

marcatcid, 2025-09-15:
Hi @mmohsinm-1, I did not receive any response but I continued investigating and solved the issue; it was a misunderstanding between ASCII and HEX representations. I must say, that the documentation was quite confusing for me and I think it would be good to have a clearer explanation of this point, so that people do not need to struggle to make it work.

The main issue is that the data that is transmitted once after the command "AT+TXDATA=24" needs to be the addresses and the message in HEX.
As I was using a serial terminal, If the message "8259137C9EC88259138a6338303031323334353637383930" is sent "as is" in the terminal, values are interpreted as ASCII chars not has HEX bytes. So, what needs to be provided in the terminal is the ASCII representation of the hex (for the MACs and for the message); as it is done in the broadcast example "111111000000001234567890" However, for the unicast MAC addresses some of the hex values will correspond to non-printing chars; what makes it difficult to provide an ASCII representation. Some serial terminals (not all) allow you to directly provide an HEX string; this would be the easiest approach; in my case, with YAT, it worked with \h(8259137C9EC88259138a6338303031323334353637383930).

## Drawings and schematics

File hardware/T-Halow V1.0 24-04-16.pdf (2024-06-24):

Battery Interface | 输入电压4.4-6V
18650_Battery | 3

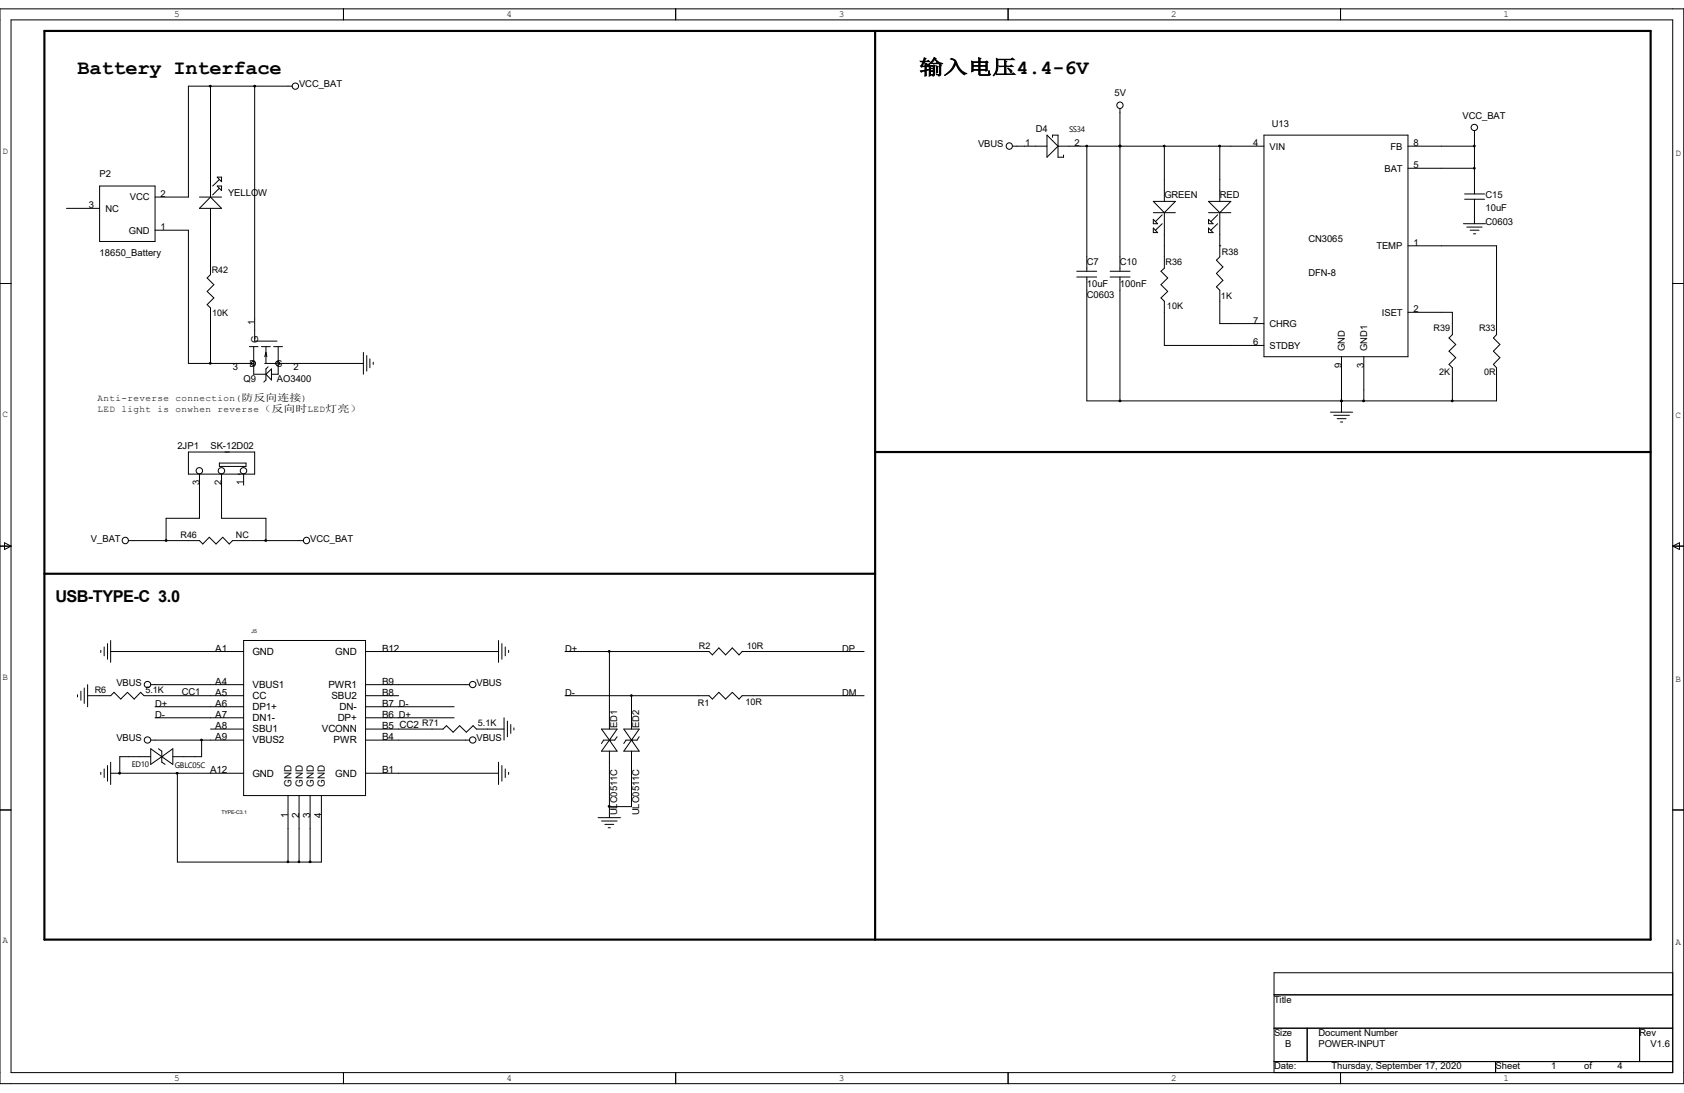
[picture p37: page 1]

Anti-reverse connection(防反向连接)
LED light is onwhen reverse（反向时LED灯亮）

Size B | Document Number POWER-INPUT | Rev V1.6

Date: Thursday, September 17, 2020 | Sheet 1 4 of

Core | Connector

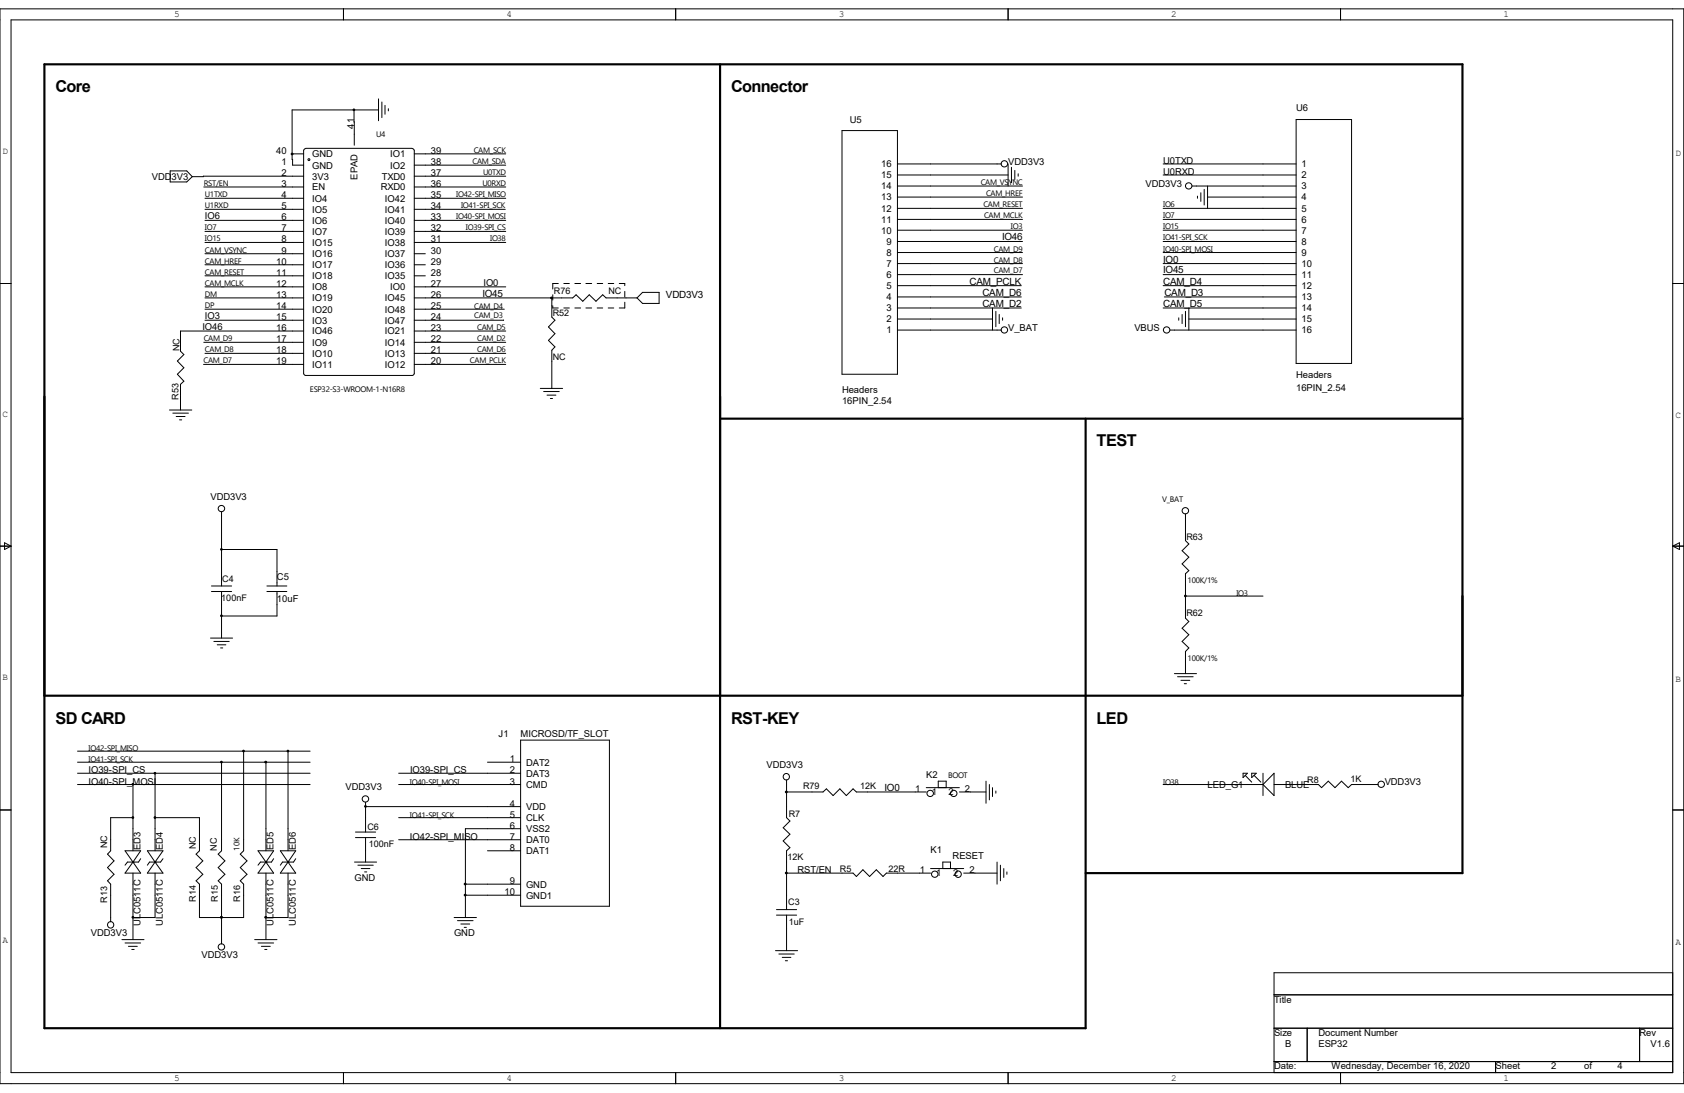
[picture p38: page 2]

TEST V_BAT

SD CARD J1 MICROSD/TF_SLOT | RST-KEY VDD3V3 K2 BOOT | LED

Size | Document Number ESP32 | Rev V1.6

Wednesday, December 16, 2020 | 2 4

MICRO-USB | TX-AH-R900P

# TX-AH-R900P R¹¹ ²²R R¹² ²²R R¹⁷ ²²R R¹⁸ ²²R R¹⁹ ²²R R²⁰ ²²R FB1 600R@¹⁰⁰M FB2 600R@¹⁰⁰M

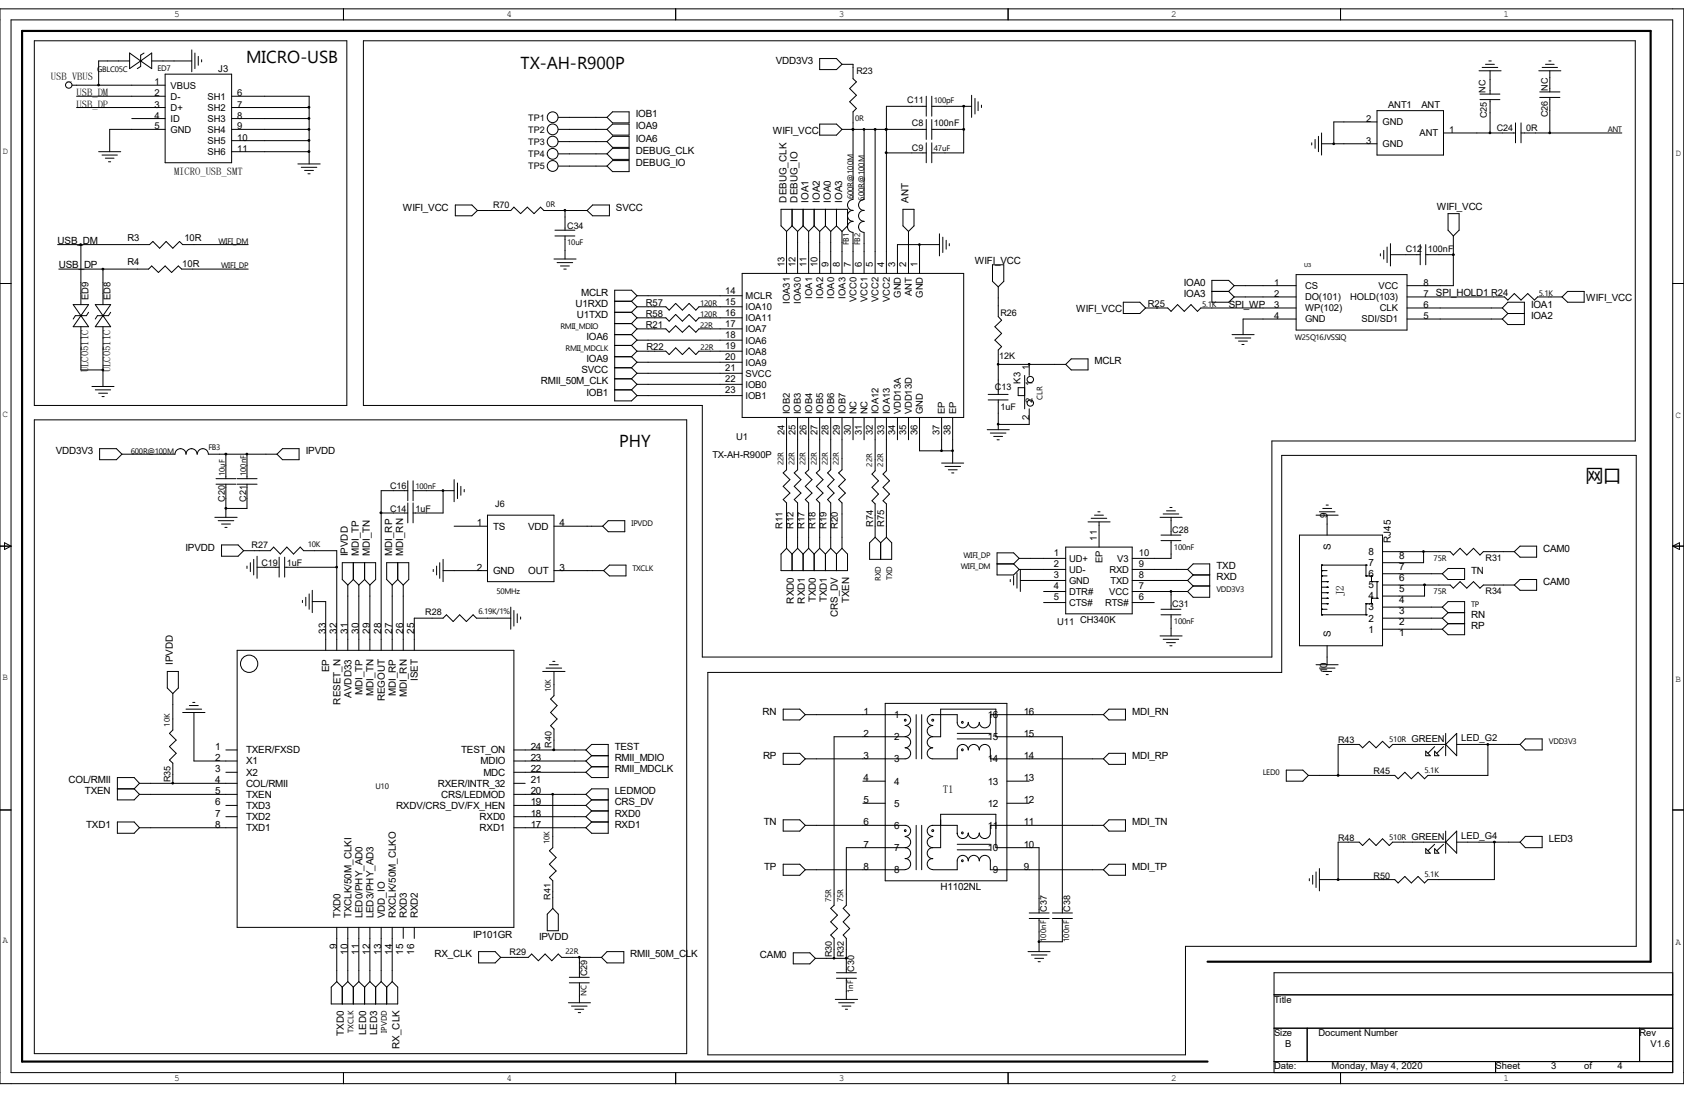
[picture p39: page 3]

9 IOA0 10 IOA2 11 IOA1 12 IOA30 13 IOA31 14 MCLR 15 IOA10 16 IOA11 17 IOA7 18 IOA6 19 IOA8 20 IOA9 21 SVCC 22 IOB0 23 IOB1 24 IOB2 25 IOB3 26 IOB4 27 IOB5 28 IOB6 29 IOB7 30 NC 31 NC 32 IOA12 33 IOA13 34 VDD13A 35 VDD13D 36 GND 37 EP 38 EP

24 TEST_ON ²⁵ ISET 26 MDI_RN ²⁷ MDI_RP ²⁸ REGOUT 29 MDI_TN ³⁰ MDI_TP ³¹ AVDD³³ ³² RESET_N ³³ EP

Size B V1.6 | Document Number | Rev

Date: Monday, May 4, 2020 | Sheet 3 4 of

# DC-DC

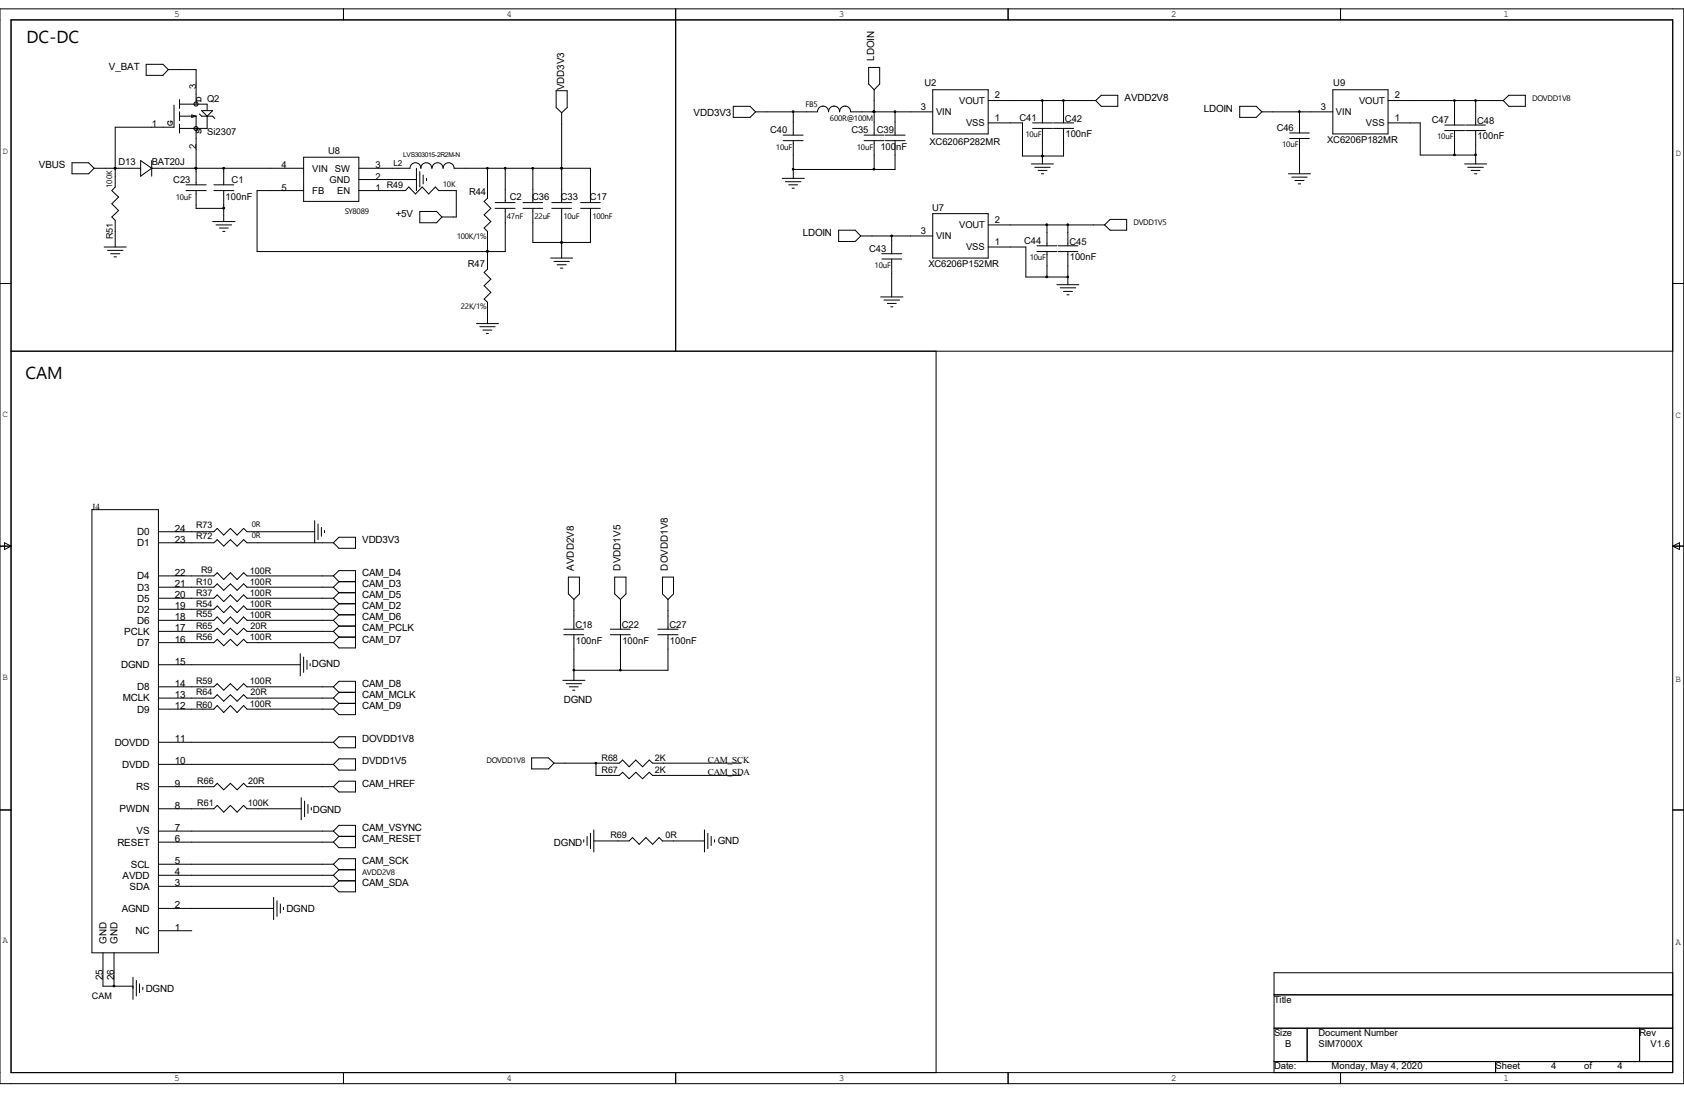
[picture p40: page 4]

Size | Document Number SIM7000X | Rev V1.6

Monday, May 4, 2020 | 4 4

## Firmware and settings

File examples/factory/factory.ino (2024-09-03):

#include "utilities.h"
#include <SPI.h>
#include <Wire.h>
#include <Adafruit_GFX.h>
#include <Adafruit_SSD1306.h>

#include "FS.h"
#include "SD.h"
#include "SPI.h"
#include "esp_camera.h"

#define BUF_MAX_LEN 20

#define AH_Rx00P_RESPONE_OK 1
#define AH_Rx00P_RESPONE_ERROR 2

bool ssd1306_ret = false;
bool camera_ret = false;
bool sdcard_ret = false;
bool tx_ah_ret = false;
char buf[BUF_MAX_LEN] = {0};

camera_config_t config;
Adafruit_SSD1306 display = Adafruit_SSD1306(128, 64, &Wire);
SemaphoreHandle_t debuglock;

//************************************[ SSD1306 ]******************************************
bool ssd1306_init(void)
{
    Serial.println("OLED FeatherWing test");
    Wire.beginTransmission(0x3C);
    if (Wire.endTransmission() == 0)
    {
        display.begin(SSD1306_SWITCHCAPVCC, 0x3C);
        return true;
    }
    return false;
}
//************************************[ SDCARD ]******************************************
bool sdcard_init(void)
{
    if (!SD.begin(TF_SPI_CS))
    {
        Serial.println("Card Mount Failed");
        return false;
    }
    uint8_t cardType = SD.cardType();

    if (cardType == CARD_NONE)
    {
        Serial.println("No SD card attached");
        return false;
    }
    Serial.print("SD Card Type: ");
    if (cardType == CARD_MMC)
    {
        Serial.println("MMC");
    }
    else if (cardType == CARD_SD)
    {
        Serial.println("SDSC");
    }
    else if (cardType == CARD_SDHC)
    {
        Serial.println("SDHC");
    }
    else
    {
        Serial.println("UNKNOWN");
    }

    uint64_t cardSize = SD.cardSize() / (1024 * 1024);
    Serial.printf("SD Card Size: %lluMB\n", cardSize);

    return true;
}

//************************************[ TX-AH ]******************************************
#if 1
int8_t waitResponse(uint32_t timeouts, String &data, const char *r1 = "OK", const char *r2 = "ERROR")
{
    int index = 0;
    uint32_t start_tick = millis();

    do {
        while (SerialAT.available() > 0) {
            int a = SerialAT.read();
            if (a < 0)
                continue; // Skip 0x00 bytes, just in case

            data.reserve(1024);
            data += static_cast<char>(a);

            // SerialMon.println(data.c_str());

            if(data.endsWith(r1)){
                index = AH_Rx00P_RESPONE_OK;
                SerialMon.println(data.c_str());
                goto finish;
            } else if(data.endsWith(r2)){
                index = AH_Rx00P_RESPONE_ERROR;
                SerialMon.println(data.c_str());
                goto finish;
            }
        }
    } while (millis() - start_tick < timeouts);

finish:
    return index;
}

int8_t waitResponse(uint32_t timeouts)
{
    String data;
    return waitResponse(timeouts, data);
}
int8_t waitResponse(void)
{
    return waitResponse(1000);
}
void sendAT(String s)
{
    s = "AT" + s;
    SerialAT.write(s.c_str());
}
bool TX_AH_init(void)
{
    int at_cnt = 0;
    // sendAT("+SYSDBG=LMAC,0");
    // waitResponse() == AH_Rx00P_RESPONE_OK ? at_cnt : at_cnt++;
    // sendAT("+BSS_BW=8");
    // waitResponse() == AH_Rx00P_RESPONE_OK ? at_cnt : at_cnt++;

    // sendAT("+SYSDBG=LMAC,0");
    // if(waitResponse() == AH_Rx00P_RESPONE_OK) SerialMon.println("AT+SYSDBG SUCCEED");
    // else SerialMon.println("AT+SYSDBG ERROR");

    // sendAT("+BSS_BW=8");
    // if(waitResponse() == AH_Rx00P_RESPONE_OK) SerialMon.println("AT+BSS_BW SUCCEED");
    // else SerialMon.println("AT+BSS_BW FAILD");


    sendAT("+SYSDBG=LMAC,0");
    if (waitResponse() == AH_Rx00P_RESPONE_OK)
        SerialMon.println("AT+SYSDBG SUCCEED");
    else
    {
        at_cnt++;
        SerialMon.println("AT+SYSDBG ERROR");
    }

    sendAT("+BSS_BW=8");
    if (waitResponse() == AH_Rx00P_RESPONE_OK)
        SerialMon.println("AT+BSS_BW SUCCEED");
    else
    {
        at_cnt++;
        SerialMon.println("AT+BSS_BW FAILD");
    }

    sendAT("+MODE=AP");
    if (waitResponse() == AH_Rx00P_RESPONE_OK)
        SerialMon.println("AT+MODE=AP SUCCEED");
    else
    {
        at_cnt++;
        SerialMon.println("AT+MODE=AP FAILD");
    }

    return (at_cnt == 0);
}
#endif
//************************************[ CAMERA ]******************************************
bool camera_init(void)
{
    config.ledc_channel = LEDC_CHANNEL_0;
    config.ledc_timer = LEDC_TIMER_0;
    config.pin_d0 = CAMERA_PIN_Y2;
    config.pin_d1 = CAMERA_PIN_Y3;
    config.pin_d2 = CAMERA_PIN_Y4;
    config.pin_d3 = CAMERA_PIN_Y5;
    config.pin_d4 = CAMERA_PIN_Y6;
    config.pin_d5 = CAMERA_PIN_Y7;
    config.pin_d6 = CAMERA_PIN_Y8;
    config.pin_d7 = CAMERA_PIN_Y9;
    config.pin_xclk = CAMERA_PIN_XCLK;
    config.pin_pclk = CAMERA_PIN_PCLK;
    config.pin_vsync = CAMERA_PIN_VSYNC;
    config.pin_href = CAMERA_PIN_HREF;
    config.pin_sccb_sda = CAMERA_PIN_SIOD;
    config.pin_sccb_scl = CAMERA_PIN_SIOC;
    config.pin_pwdn = CAMERA_PIN_PWDN;
    config.pin_reset = CAMERA_PIN_RESET;
    config.xclk_freq_hz = XCLK_FREQ_HZ;
    config.pixel_format = PIXFORMAT_JPEG;
    config.frame_size = FRAMESIZE_96X96;
    config.jpeg_quality = 12;
    config.fb_count = 1;
    config.fb_location = CAMERA_FB_IN_DRAM;
    config.grab_mode = CAMERA_GRAB_WHEN_EMPTY;

    if (config.pixel_format == PIXFORMAT_JPEG)
    {
        if (psramFound())
        {
            config.jpeg_quality = 10;
            config.fb_count = 2;
            config.grab_mode = CAMERA_GRAB_LATEST;
        }
        else
        {
            // Limit the frame size when PSRAM is not available
            config.frame_size = FRAMESIZE_SVGA;
            config.fb_location = CAMERA_FB_IN_DRAM;
        }
    }

    // camera init
    esp_err_t err = esp_camera_init(&config);
    if (err != ESP_OK)
    {
        Serial.printf("Camera init failed with error 0x%x", err);
        return false;
    }
    return true;
}
//************************************[ Other fun ]******************************************
char *line_align(char *buf, const char *str1, const char *str2)
{
    int max_line_size = BUF_MAX_LEN - 1;
    int16_t w2 = strlen(str2);
    int16_t w1 = max_line_size - w2;
    snprintf(buf, BUF_MAX_LEN, "%-*s%-*s", w1, str1, w2, str2);
    return buf;
}

bool tx_ah_conn_status = false;
char rssi_buf[16];

void lcd_info_show(void)
{
    if (ssd1306_ret == false)
    {
        Serial.println("******************************");
        Serial.println((tx_ah_ret == true ? "TX-AH   PASS" : "TX-AH    ---"));
        Serial.println((ssd1306_ret == true ? "SSD1306 PASS" : "SSD1306  ---"));
        Serial.println((sdcard_ret == true ? "SDCard  PASS" : "SDCard   ---"));
        Serial.println((camera_ret == true ? "CAMERA  PASS" : "CAMERA   ---"));
        Serial.println(" ");

        Serial.println(line_align(buf, "Role:", "AP "));

        if (tx_ah_conn_status) {
            Serial.println(line_align(buf, "RSSI:", rssi_buf));
        } else {
            Serial.println("Disconnect!!!");
        }
    } else {
        // Clear the buffer.
        display.clearDisplay();
        display.display();
        display.setTextSize(1);
        display.setTextColor(SSD1306_WHITE);
        display.setCursor(0, 0);
        display.println(line_align(buf, "LCD:", (ssd1306_ret == true ? "PASS" : "---")));
        display.println(line_align(buf, "SD:", (sdcard_ret == true ? "PASS" : "---")));
        display.println(line_align(buf, "CAM:", (camera_ret == true ? "PASS" : "---")));
        display.println(line_align(buf, "AH:", (tx_ah_ret == true ? "PASS" : "---")));
        display.println(" ");

        display.println(line_align(buf, "Role:", "AP "));

        if (tx_ah_conn_status) {
            display.println(line_align(buf, "RSSI:", rssi_buf));
        } else {
            display.println("Disconnect!!!");
        }
        display.display();
    }
}

void setup()
{
    Serial.begin(115200);

    delay(3000);

    debuglock = xSemaphoreCreateBinary();
    assert(debuglock);
    xSemaphoreGive(debuglock);

    Wire.begin(BOARD_I2C_SDA, BOARD_I2C_SCL);
    SPI.begin(TF_SPI_SCK, TF_SPI_MISO, TF_SPI_MOSI, TF_SPI_CS);
    SerialAT.begin(115200, SERIAL_8N1, SERIAL_AT_RXD, SERIAL_AT_TXD);

    ssd1306_ret = ssd1306_init();
    camera_ret = camera_init();
    sdcard_ret = sdcard_init();
    tx_ah_ret = TX_AH_init();

    // if (ssd1306_ret)
    // {
        lcd_info_show();
    // }
    pinMode(BOARD_LED, OUTPUT);
}

uint32_t last_tick = 0;
uint32_t rssi_tick = 0;

String str;
int indx = 0;
bool led_flag = 0;

void loop()
{
    if (millis() - last_tick > 1000)
    {
        last_tick = millis();
        digitalWrite(BOARD_LED, led_flag);
        led_flag = !led_flag;
    }

    if (millis() - rssi_tick > 3000)
    {
        rssi_tick = millis();

        String data;
        sendAT("+CONN_STATE");
        if (waitResponse(1000, data, "+CONNECTED", "+DISCONNECT") == AH_Rx00P_RESPONE_OK) {
            tx_ah_conn_status = true;
        }
        else {
            tx_ah_conn_status = false;
        }

        if(tx_ah_conn_status) {
            String rssi_data;
            sendAT("+RSSI=1");
            if (waitResponse(1000, rssi_data) == AH_Rx00P_RESPONE_OK) {
                int startIndex = rssi_data.indexOf(':');
                int endIndex = rssi_data.lastIndexOf('\n');
                String substr = rssi_data.substring(startIndex + 1, endIndex);
                strcpy(rssi_buf, substr.c_str());
            }
        }

        lcd_info_show();
    }

    while (SerialAT.available())
    {
        SerialMon.write(SerialAT.read());
    }
    while (SerialMon.available())
    {
        SerialAT.write(SerialMon.read());
    }
    delay(1);
}

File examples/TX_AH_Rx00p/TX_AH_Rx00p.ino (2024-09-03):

#include <Arduino.h>
#include "utilities.h"
#include <stdio.h>
#include <string.h>

#include "FS.h"
#include "SD.h"
#include "SPI.h"


#define AH_Rx00P_ALL_CMD "A+"
#define AH_Rx00P_SYSDBG "AT+SYSDBG=LMAC,0";

#define AH_Rx00P_RESPONE_OK    1
#define AH_Rx00P_RESPONE_ERROR 2


String str_at = "";
String str_dbg= "";

uint8_t target_addr[6] = {0xba, 0x04, 0x59, 0xa0, 0x7a, 0x68};
uint8_t source_addr[6] = {0xba, 0x04, 0x59, 0x8c, 0x94, 0x68};
uint8_t protocol_type[2] = {0xff, 0xff};

char protocol_head[14]={
    0xba, 0x04, 0x59, 0xa0, 0x7a, 0x68,
    0xba, 0x04, 0x59, 0x8c, 0x94, 0x68, 
    0xff, 0xff
};

char protocol_head_1[14] = {
    0x31, 0x31, 0x31, 0x31, 0x31, 0x31, 
    0x30, 0x30, 0x30, 0x30, 0x30, 0x30, 
    0x30, 0x30
};

char send_buf[128];


char sendTestBuf[] =    "The above, if you register, allows you down the bottom of "
                        "that page to download hgSDK-v1.6.3.6-25403-IoT-NDEV which is"
                        " the SDK (source code) for this module. Don't get too excited,"
                        " though - the \"RF\" side of things is inside a binary .a blob"
                        " (libtxw4002a.a) which is linked at linking time. The header "
                        "for the RF bits is \"libwnb.h\"."
                        "The above, if you register, allows you down the bottom of "
                        "that page to download hgSDK-v1.6.3.6-25403-IoT-NDEV which is"
                        " the SDK (source code) for this module. Don't get too excited,"
                        " though - the \"RF\" side of things is inside a binary .a blob"
                        " (libtxw4002a.a) which is linked at linking time. The header "
                        "for the RF bits is \"libwnb.h\"."
                        "The above, if you register, allows you down the bottom of "
                        "that page to download hgSDK-v1.6.3.6-25403-IoT-NDEV which is"
                        " the SDK (source code) for this module. Don't get too excited,"
                        " though - the \"RF\" side of things is inside a binary .a blob"
                        " (libtxw4002a.a) which is linked at linking time. The header "
                        "for the RF bits is \"libwnb.h\".";
void sendTest(const char *buf, uint32_t len)
{
    String cmd = "+TXDATA=";
    cmd.concat(len+14);
    SerialMon.println(cmd);
    sendAT(cmd);
    int ret = waitResponse();
    if(ret == AH_Rx00P_RESPONE_OK){
        SerialAT.write((const char*)protocol_head_1, 14);
        SerialAT.write((const char*)buf, len);
    }else if(ret == AH_Rx00P_RESPONE_ERROR) {
        SerialMon.println("AT+TXDATA send value error!");
    }
}

void sendValue(const char *buf, uint32_t len)
{
    String cmd = "+TXDATA=";
    cmd.concat(len+14);
    SerialMon.println(cmd);
    sendAT(cmd);
    int ret = waitResponse();
    if(ret == AH_Rx00P_RESPONE_OK){
        SerialAT.write((const char*)protocol_head_1, 14);
        SerialAT.write((const char*)buf, len);

        // memcpy((void*)send_buf, (const void*)protocol_head_1, 14);
        // memcpy((void*)(send_buf+14), (const void*)buf, len);
        // SerialAT.write((const char *)send_buf, 14+len);
        // SerialMon.write((const char *)send_buf, 14+len);
        // for(int i = 0; i < 24; i++){
        //     SerialMon.print(send_buf[i]);
        // }

        ret = waitResponse();
        if(ret == AH_Rx00P_RESPONE_OK){
            SerialMon.println("AT+TXDATA send value OK!");
        }else if(ret == AH_Rx00P_RESPONE_ERROR){
            SerialMon.println("AT+TXDATA send value ERROR!");
        }
    } else if(ret == AH_Rx00P_RESPONE_ERROR) {
        SerialMon.println("AT+TXDATA send value error!");
    }
}

void sendAT(String s)
{
    s = "AT" + s;
    SerialAT.write(s.c_str());
}

int8_t waitResponse(uint32_t timeouts, String& data, const char *r1 = "OK", const char *r2 = "ERROR")
{
    int index = 0;
    uint32_t start_tick = millis();
    do{
        while (SerialAT.available() > 0) {
            int a = SerialAT.read();
            if(a < 0) continue; // Skip 0x00 bytes, just in case

            data.reserve(1024);
            data += static_cast<char>(a);
            
            if(data.endsWith(r1)){
                index = 1;
                goto finish;
            } else if(data.endsWith(r2)){
                index = 2;
                goto finish;
            }
        }
    }while(millis() - start_tick < timeouts);
    
finish:
    return index;
}   

int8_t waitResponse(uint32_t timeouts)
{
    String data;
    return waitResponse(timeouts, data);
}

int8_t waitResponse(void)
{
    return waitResponse(1000);
}


String inStr = "";
String atStr = "";
void GetSerialCmd()
{
        while (Serial.available()) {
            inStr += (char)Serial.read();
        }
        while (SerialAT.available()) {
            atStr += (char)SerialAT.read();
        }

    if(atStr != ""){
        SerialMon.println(atStr);
        atStr = "";
    }
    
    if (inStr != "") {
        // Serial.print("input: ");
        // Serial.println(inStr);

        switch ((byte)inStr[0])
        {
        case '1':{
            sendAT("+MODE");
            if(waitResponse() == 1) Serial.println("AT+MODE SUCCEED");
            else Serial.println("AT+MODE FAILD");
            break;
        }
        case '2':{
            String data;
            sendAT("+CONN_STATE");
            int8_t r = waitResponse(1000, data, "+CONNECTED", "+DISCONNECT");
            Serial.println("+CONN_STATE" + data);
            break;
        }
        case '3':{
            String data;
            sendAT("+MAC_ADDR=?");
            int8_t r = waitResponse(100, data);
            Serial.println(data);
            break;
        }
        case '4':{
            const char *buf = inStr.c_str();
            int len = strlen(buf);
            // sendValue(buf, len);
            sendTest(sendTestBuf, strlen(sendTestBuf));
            break;
        }
        default:
            break;
        }
        inStr = "";
    }
}


void AH_RX00P_init(void)
{
    sendAT("+SYSDBG=LMAC,0");
    if(waitResponse() == 1) SerialMon.println("AT+SYSDBG SUCCEED");
    else SerialMon.println("AT+SYSDBG ERROR");

    sendAT("+BSS_BW=8");
    if(waitResponse() == 1) SerialMon.println("AT+BSS_BW SUCCEED");
    else SerialMon.println("AT+BSS_BW FAILD");
}

void setup()
{
    Serial.begin(115200);
    Serial.setDebugOutput(true);

    SerialAT.begin(115200, SERIAL_8N1, SERIAL_AT_TXD, SERIAL_AT_RXD);

    int start_delay = 2;
    while (start_delay)
    {
        Serial.print(start_delay);
        delay(1000);
        start_delay--;
    }

    AH_RX00P_init();
}

uint32_t last_tick = 0;
bool led_flag = 0;
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

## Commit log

2024-06-24 feat：add factory test
2024-06-26 feat：Add firmware
2024-06-27 fix：Modify pairing Settings
2024-06-28 style：Delete redundant files
2024-07-06 test：Update firmware
2024-07-19 docs：Add README_CN
2024-07-19 fix：Document not found image
2024-07-19 docs：Add README.md
2024-07-30 docs：Update TX_AH documentation
2024-07-30 docs：Add bridge instructions
2024-08-05 build：Update bridge firmware
2024-08-06 docs：Update documentation
2024-08-12 docs：Describe two working modes
2024-08-20 fix：Update the SDK to eliminate compilation errors
2024-08-23 fix：Fixed OV5640 camera not having a picture
    [CameraWebServer.ino]
2024-08-24 fix：Modified esp32 configuration
2024-08-24 perf：Delete the SDK intermediate file
2024-09-03 fix：platformio.ino
2024-09-03 fix：compile error
2024-09-05 docs：Add EMC authentication docs
2024-09-06 Update esp32 firmware
2024-09-18 Add DXF files
    [T-Halow V1.0 - BOTTOM.dxf, T-Halow V1.0 - TOP.dxf]
2024-10-14 docs：UPdate AT document
2024-10-15 dosc：Update some documents
2024-10-16 docs：dosc：Update documents
2024-10-16 feat：Add issue.yml
2024-10-16 dosc：Update documents
